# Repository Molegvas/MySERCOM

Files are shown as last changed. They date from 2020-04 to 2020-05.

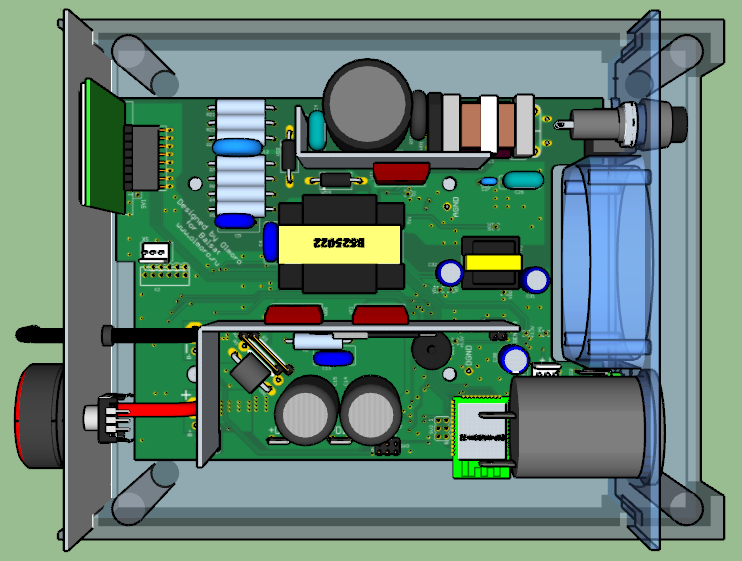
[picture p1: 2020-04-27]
documents/resources/D20v05top.png

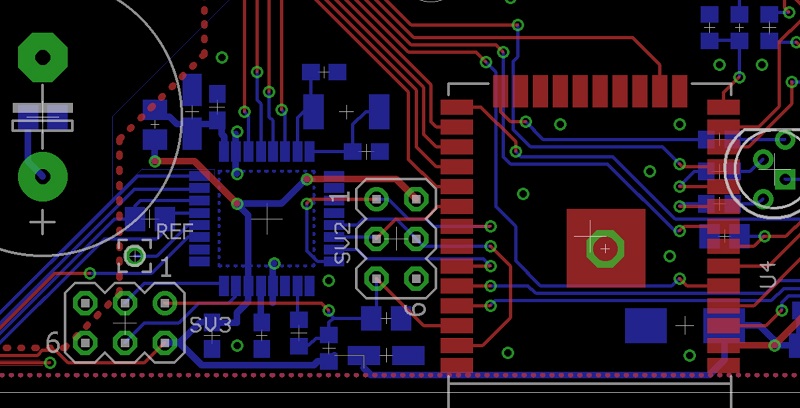
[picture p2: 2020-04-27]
documents/resources/driver.jpg

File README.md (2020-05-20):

#          Адаптер силового блока зарядного устройства

##   Кратко 

Адаптер силового блока предназначен для соединения управляющего контроллера с силовым блоком. Центральный микроконтроллер освобождается от исполнения рутинных операций.

 ### Аппаратная поддержка
   Прототипирование выполнялось на плате SAMD21-M0-Mini. Подробности включения хорошо описаны в https://github.com/BLavery/SAMD21-M0-Mini.
  К сожалению поддержка Arduino не в полной мере соответствует потребностям проекта, но это преодолимо.

 #### Особенности прототипирования на плате SAMD21-M0-Mini
  В качестве инструкции:  https://github.com/BLavery/SAMD21-M0-Mini:
 * select the board: Tools/Board = Arduino SAMD / "Arduino Zero (Native USB Port)".
 * Double-click the board reset button. Upload. See if a LED blinks.
 explain a bit:
 1. The Arduino bootloader uses double click on reset button to enter flash upload mode. Single
    reset enters normal running mode.
 2. The serial/bossac mode of USB upload is included in the Arduino install.
 3. The regular user LED is missing. So we choose one of the TX/RX LEDs. For the moment, 
    the Arduino sketch is NOT otherwise driving these as TX/RX indicators (see above), 
    so we can re-employ them.
 4. But what pin or GPIO number? For this board, reference the pins as 0-26 or A0-A5. Not D25, 
    nor PB03 or PB3.

 ### Обмен между контроллерами.

*  Протокол WAKE является логическим уровнем интерфейса управления оборудованием с помощью асинхронного последовательного канала. Физический уровень интерфейса протоколом не определяется, может использоваться, например, RS-232, RS-485 или USB. Протокол позволяет производить обмен пакетами данных (data frames) длиной до 255 байт с адресуемыми устройствами, которых может быть до 127. Формат данных может быть любым. Могут передаваться байтовые поля, многобайтовые слова или строки символов. Для контроля правильности передачи данных используется контрольная сумма (CRC-8).
* Подробная информация о WAKE: http://leoniv.diod.club/articles/wake/wake.html
Выбор этого протокола объясняется тем, что хорошо известен автору и многолетней работой доказал свою надежность в устройстве ротации кондиционеров.
* Первоначальные планы использовать в качестве физического носителя SPI разбились о прозу жизни - в наличии не оказалось соответствующего адаптера USB-3SPI. Для целей прототипирования используется USB-UART терминал WakeUp! от Ридико Леонида Ивановича. Найдете в "resources".
* Передача параметров из нескольких байт: сначала старший, потом младшие.
* Время ожидания ответа ограничено 1000мс.  

 ### Управление измерениями.

 #### Измерение напряжения
   Измерение напряжения предполагается в диапазоне от -0,2В до +20,0В. Режим АЦП - дифференциальный. Опорное напряжение и усиление - выбор есть. Если получится реализовать вариант со сдвигом по напряжению на 200мВ минусовой клеммы, то обработка неправильной полярности подключения не потребует аппаратной поддержки. 

 #### Измерение тока
   Измерение тока в диапазоне от -16 до +16 ампер на токоизмерительном шунте укладывается в диапазон входного напряжения от -160 до +160мВ. Режим АЦП - дифференциальный. Пороги аварийного отключения не выставлялись.
 #### Измерение тока разряда
Зарезервировано. 
 #### Измерение температуры
Для датчика типа MF52 B 3950 NTC термистор 2% 10 kOm, последовательно резистор 10 kOm, запитан от 3,3в.
Параметры по умолчанию и задаваемые командой 0x57:

| bits | ref | gain | sampl | div | comp | offset | ser Ohm | nom Ohm |
|---|-----|---|---|-----|---|---|---|---|
|  01  |  00 |  00  | 03  |  04 |  00  |  0000  |  2710 | 2710  |

Ответ: код АЦП (2 байта) и значение температур, умноженное на 100.
Вычисления производятся по формуле Стейнхарта.

* Конфигурирование канала измерения состоит из параметров АЦП (разрядность, усреднение, см. страницы 853 и 862) и датчика (опорное напряжение, усиление, приборное смещение, коэффициент преобразования данных в физическую величину).
* В ответ контроллер отправляет пакет, содержащий байт ошибки (зарезервированная позиция), двухбайтный код АЦП и двухбайтное значение измеренной величины (для напряжения - в милливольтах).
* Команды такого типа скорее исследовательские, служащие для поиска оптимальных конфигураций.
* Выбор параметров, предложенных в datasheet ... как говорится, "не все йогурты одинаково полезны" ... 
* Аппаратное смещение задается отдельной командой, усиление - не исследовалось.      
* Ниже дано пояснение формата команды на примере конфигурирования измерителя напряжения.
```c++
// Настройка измерителя напряжения (код команды 0x55  'cmd_set_adc_bat')     
void doAdcBat()
{
    if( rxNbt == 10 )		  // Проверка получения полного пакета
  {
    uint8_t err           = 0x00;
    constexpr uint8_t prb = 0x00; // Измеритель напряжения, в [] - ориентировочные параметры
      // Задать все параметры измерителя [ 01 00 00 03 04 00 0000 12BA ]
    adcBits     [prb] = rxDat[0]; // Разрешение: 0x00(12), [0x01(16)], 0x02(10),  0x03(8)
    prbReference[prb] = rxDat[1]; // Опорное:   [0x00(1V)], 0x01(1/1.48VDDA),     0x02(1/2VDDA), 0x03(ExtA)
    prbGain     [prb] = rxDat[2]; // Усиление:  [0x00(X1)], 0x01(X2),  0x03(X4),  0x04(X8),      (X16), (DIV2)    
    adcSamples  [prb] = rxDat[3]; // Накопление: 0x00(1),   0x01(2),   0x02(4),  [0x03(8)],      0x04(16), ... 0x0a
    adcDivider  [prb] = rxDat[4]; // Делитель:   0x00(2^0), 0x01(2^1), 0x02(2^2), 0x03(2^3),    [0x04(2^4)]... 0x07
    refComp    = 0x01 & rxDat[5]; // 0/1: выкл/вкл аппаратное смещение АЦП
    prbOffset   [prb] = get16(6); // Приборное смещение: 0x8000 ... 0x7fff
    prbDivider  [prb] = get16(8); // Коэффициент преобразования в милливольты:   [0x12ba]
      // Считать результат
                                          // Нулевой байт - ошибка параметра (зарезервировано)
    txDat[1] = ( adcVoltage >> 8) & 0xFF; // Hi
    txDat[2] =   adcVoltage       & 0xFF; // Lo
    txDat[3] = ( voltage >> 8)    & 0xFF; // Hi
    txDat[4] =   voltage          & 0xFF; // Lo

    txReplay( 5, err );		  // Ответ из 5 байт
  }
  else
  {
    txReplay(1, err_tx);	  // Передается код ошибки протокола
  }
}
```

 ### Управление процессами
   Управление производится через два регистра состояния (они же и регистры управления)
 #### state1
* _switchStatus          - управление коммутатором в цепи плюсовой клеммы (foff_pin)
* _converterStatus       - управление преобразователем UC3845
* _currentControlStatus  - пид-регулирование по току
* _voltageControlStatus  - пид-регулирование по напряжению
* _chargeStatus          - управление переключением аналогового выхода на заряд или разряд
* _dischargeStatus       - состояние заряд/разряд
* _pauseStatus           - пауза
* _pidStatus        	 - управление регулятором

 #### state2
* _overHeatingStatus     - состояние перегрева
* _overloadStatus        - состояние перегрузки
* _powerLimitationStatus - состояние ограничения мощности
* _reversePolarityStatus - состояние "обратная полярность"
* _shortCircuitStatus    - состояние "короткое замыкание"
* _calibrationStatus     - состояние калибровки
* _upgradeStatus         - обновление
* _reserve2Status        - резерв 2

 ### Команды управления процессами
 * 0x60 - тестовая - управление коммутатором
 * 0x61 - тестовая - управление преобразователем
 * 0x62 - тестовая - прямое управление преобразователем по напряжению
 * 0x63 - тестовая - прямое управление преобразователем по току
 * 0x64 - 

 ### PID-регулирование.

  Для прототипирования выбран быстрый 32-битный пид-регулятор с фиксированной точкой для Arduino:
FastPID v1.3.1 by Mike Matera 
https://github.com/mike-matera/FastPID

  Этот пид-регулятор работает быстрее, поскольку он позволяет избежать дорогостоящих операций с плавающей запятой. Пид-регулятор сконфигурирован с коэффициентами с плавающей запятой и переводит их в фиксированную точку внутренне. Это накладывает ограничения на область применения коэффициентов. Установка условий I и D на ноль ускоряет работу регулятора. Регулятор сконфигурирован для работы на фиксированной частоте, и вызывающий код отвечает за работу на этой частоте. Параметры Ki и Kd масштабируются по частоте, чтобы сэкономить время во время операции step(). 

 #### Описание коэффициентов регулирования

  * Kp - пропорциональный 
  * Ki - интегральный 
  * Kd - дифференциальный 
  * Hz - частота выполнения контроллера 

#### Диапазон значений коэффициентов 

Конвейер вычислений ожидает 16-битные коэффициенты. Это контролируется PARAM_BITS и не должно быть изменено, иначе может возникнуть нежелательное переполнение. Количество битов до и после десятичного знака контролируется параметром PARAM_SHIFT в FastPID.h. значение по умолчанию для PARAM_SHIFT равно 8 и может быть изменено в соответствии с вашим приложением.

  * Диапазон параметра P от 0.00390625 до 255 включительно.** 
  * Параметр I равен P / Hz** 
  * Параметр D равен P * Hz** 
* ** До выяснения реальной потребности в диапазоне диапазон P установлен от 0,01 до 255.
Регулятор проверяет наличие нарушений диапазона параметров и не будет работать, если коэффициент находится вне диапазона. Все операции конфигурации возвращают bool, чтобы предупредить пользователя об ошибке. Функция err() проверяет состояние ошибки. Ошибки можно устранить с помощью функции clear().

#### Частота Выполнения

* ** Частота выполнения не определяется автоматически, это значительно повышает производительность регулятора. Вместо этого Ki и Kd масштабируются на этапе настройки. Очень важно вызывать step() с той скоростью, которую вы укажете. 

#### Вход и выход

Входной сигнал и заданное значение являются int16_t, что соответствует разрядности АЦП и позволяет разместить отрицательные показания и заданные значения. Выходные данные PID - это int16_t. Фактическая битовая ширина и знаковость вывода могут быть настроены. 
  
  * bits - выходная ширина будет ограничена значениями внутри этого битового диапазона. Допустимые значения от 1 до 16 
  * sign если true, то выходной диапазон равен от -2^(бит-1) до -2^(бит-1) -1. Если выходной диапазон false, то от 0 до 2^(бит-1)-1. 
  * ** Максимальное выходное значение контроллера -32767 (даже в 16-битном беззнаковом режиме) ** 

#### Исполнение

Производительность FastPID варьируется в зависимости от коэффициентов. Когда коэффициент равен нулю, выполняется меньший расчет. Проверено: менее 10мкс. 

#### ПРИКЛАДНОЙ ПРОГРАММНЫЙ ИНТЕРФЕЙС (API)
Здесь и далее приводится авторский текст из указанного первоисточника с незначительными изменениями.

API стремится быть простым и понятным. Я не буду имплицировать функции в регуляторе, которые были бы лучше реализованы вне его.
```c++
FastPID()
```
Создайте контроллер по умолчанию. Все коэффициенты по умолчанию равны нулю. Не используйте сконструированный по умолчанию контроллер до тех пор, пока вы не вызовете setCoefficients() и setOutputconfig()

```c++
FastPID(float kp, float ki, float kd, float hz, int bits=16, bool sign=false)
```
Постройте контроллер, который готов к работе. Вызывает следующие вызовы:
```c++
configure(kp, ki, kd, hz, bits, sign);

bool setCoefficients(float kp, float ki, float kd, float hz);
```
Настройка ПИД коэффициентов. Коэффициенты ki и kd масштабируются на величину hz. Значение hz информирует PID о скорости, которую вы назовете step(). Вызывающий код отвечает за вызов step() со скоростью в hz. Возвращает значение false, если произошла ошибка конфигурации. Что может быть связано с предыдущим вызовом.

bool setOutputConfig(int bits, bool sign);

Установите конфигурацию ouptut по битам/знаку. Диапазон выхода будет следующим:

Для знака, равного true  2^(n-1) - 1 вниз до -2^(n-1)

Для знака, равного false  2^n-1 вниз до 0

* ** bits равен 16-это особый случай. 
* ** Когда bits равен 16 и знак false диапазон выходных напряжений 32767 до 0

Возвращает значение false, если произошла ошибка конфигурации. Что может быть связано с предыдущим вызовом.
```c++
bool setOutputRange (int16_t min, int16_t max);
```
Установите диапазон ouptut непосредственно. Эффективный диапазон действия составляет:

* Мин:  от -32768 до 32766
* Макс: от -32767 до 32767

Min должно быть больше, чем max.

Возвращает значение false, если произошла ошибка конфигурации. Что может быть связано с предыдущим вызовом.
```c++
void clear();
```
Перезагрузите контроллер. Это должно быть сделано до того, как вы каким-либо образом измените конфигурацию.
```c++
bool configure(float kp, float ki, float kd, float hz, int bits=16, bool sign=false);
```
Массовая настройка контроллера. Эквивалентный:
```c++
clear();
setCoefficients(kp, ki, kd, hz);
setOutputConfig(bits, sign);

int16_t step(int16_t sp, int16_t fb);
```
Выполните один шаг контроллера и верните следующий вывод.
```c++
bool err();
```
Проверьте наличие ошибки конфиурации. Контроллер не будет работать, если эта функция возвращает true. 

#### Целочисленный Завод 

Приложения, которые управляют медленно движущимися системами и имеют ненулевой интегральный член, часто видят значительное превышение при запуске. 
Это вызвано интегральной суммой winidng up, поскольку она помнит долгое время вдали от заданной точки. Если это описывает вашу систему есть две вещи, которые вы можете сделать. 

##### Заводную решение: ограничить сумму 

В FastPID есть константы.h, которые контролируют максимально допустимый Интеграл. Понижение этих параметров предотвращает выход контроллера из строя. 
запоминание как можно большего смещения от заданного значения и позволит уменьшить превышение. 
```c++
#define INTEG_MAX    (INT32_MAX)
#define INTEG_MIN    (INT32_MIN)
```
Меняйте эти константы с осторожностью. Установка их слишком низко исправит вашу проблему превышения скорости, но это негативно скажется на способность регулятора регулировать нагрузку. Если вы не уверены в правильной константе используйте следующее решение вместо этого ограничения суммы. 

#### Ограничение Заводки: Ограниченное Регулирование 

Пид-контроллер лучше всего работает, когда система находится близко к заданному значению. Во время фазы запуска или в случае с a 
значительная экскурсия, вы можете полностью отключить пид-контроль. Пример этого можно найти в контроллере Sous-Vide 
пример в этом проекте. Ядро логики находится в этом коде: 
```c++
if (feedback < (setpoint * 0.9)) {
  analogWrite(PIN_OUTPUT, 1);
  myPID.clear();
}
else {
  analogWrite(PIN_OUTPUT, myPID.step(setpoint, feedback));
}
```
Код обходит ПИД, когда температура составляет менее 90% от заданного значения, просто включив нагреватель. Когда 
температура выше 90% от заданного значения пид включен. Фиксация вашего промаха таким образом дает вам гораздо лучший контроль
вашей системы без необходимости добавлять сложные, недопустимые и трудные для понимания функции к пид-контроллеру.

#### Sample Code 
```c++
#include <FastPID.h>

#define PIN_INPUT     A0
#define PIN_SETPOINT  A1
#define PIN_OUTPUT    9

float Kp=0.1, Ki=0.5, Kd=0.1, Hz=10;
int output_bits = 8;
bool output_signed = false;

FastPID myPID(Kp, Ki, Kd, Hz, output_bits, output_signed);

void setup()
{
  Serial.begin(9600);
  if (myPID.err()) {
    Serial.println("There is a configuration error!");
    for (;;) {}
  }
}

void loop()
{
  int setpoint = analogRead(PIN_SETPOINT) / 2; 
  int feedback = analogRead(PIN_INPUT);
  int ts = micros();
  uint8_t output = myPID.step(setpoint, feedback);
  int tss = micros();
  analogWrite(PIN_OUTPUT, output);
  Serial.print("(Fast) micros: "); 
  Serial.print(tss - ts);
  Serial.print(" sp: "); 
  Serial.print(setpoint); 
  Serial.print(" fb: "); 
  Serial.print(feedback);
  Serial.print(" out: ");
  Serial.println(output);
  delay(100);
}
```
### Справочная информация (подлежит уточнению)

|  код  | имя | параметры | пример (данные, hex) |
|---|---|---|---|
| ответ	| 			  | cmd_err  			 | ошибка приема пакета |

#### Команды АЦП-преобразований

|  код  | имя | параметры | пример (данные, hex) |
|---|---|---|---|
| 0x50	| cmd_adc_read_probes | | |
| ответ	| 			  | adcU_h,l, adcI_h,l, 	 | 1F 00 1F 00 |
| 	| 			  | adcD_h,l, adcC_h,l, | 1F 00 1F 00 |
| | | mcr1, mcr2 | 00 FF |
| 0x52	| cmd_adc_config52 | nPrb, gain, ref, offset, mult | 01 00 02 00 00 01 00 |
| ответ	| 			  | | 00 |
| 0x53	| cmd_adc_config53 | nPrb, bits, samples, divider | 01 01 02 03 |
| ответ	| 			  | | 00 |
| | | | | 

#### Команды ПИД-регулятора

|  код  | имя | параметры | пример (данные, hex) |
|---|---|---|---|
| 0x40	| cmd_pid_configure | kp, ki, kd, hz, bits, sign | 00 19 00 80 00 00 0A 00 00 0A 00 |
| ответ	| 			  | 00 / 0x40 | OK / ошибка параметра |
| 0x41	| cmd_pid_coefficients | kp, ki, kd, hz | 00 19 00 80 00 00 0A 00 |
| ответ	| 			  | 00 / 0x40 | OK / ошибка параметра |
| 0x42	| cmd_pid_output_range | min, max | 00 00 03 FF |
| ответ	| 			  | 00 / 0x40 | OK / ошибка параметра |
| 0x43	| cmd_pid_output_config | bits, sign | 10 00 |
| ответ	| 			  | 00 / 0x40 | OK / ошибка параметра |
| 0x44	| cmd_pid_clear | | |
| ответ	| 			  | 00 / 0x40 | OK / ошибка параметра |
| 0x45	| cmd_pid_stop_go | (стоп-пауза-пуск) | |
| ответ	| 			  | 00 / 0x40 | OK / ошибка |
| 0x46	| cmd_pid_test | res, mode, setpoint, min, max | FF 03 01 FF 00 00 03 FF |
| ответ	| 			  | 00 / 0x40 | OK / ошибка параметра |
| 0x47	| | | |
| | | | | 
* kp, ki, kd, hz - целочисленные, полученные умножением на 256 (т.е << 8)

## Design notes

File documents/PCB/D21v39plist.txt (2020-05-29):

Partlist

Exported from D21_v39.sch at 29.05.2020 8:06

EAGLE Version 7.3.0 Copyright (c) 1988-2015 CadSoft

Assembly variant: 

Part     Value                    Device                        Package               Library                Sheet

(X2)                              MA05-1                        MA05-1                con-lstb_moro          3
+        +                        WIREPAD8_3                    WIREPAD8_3            Q921s                  3
+3.3V                             WIREPAD1,6/0,8                1,6/0,8               wirepad                2
+5.5V                             WIREPAD1,6/0,8                1,6/0,8               wirepad                2
-        -                        WIREPAD8_3                    WIREPAD8_3            Q921s                  3
5        TPB1,27                  TPB1,27                       B1,27                 testpad                1
AGND                              WIREPAD4,16O1,6               4,16O1,6              wirepad                1
B+                                WIREPAD4,16O1,6               4,16O1,6              wirepad                3
B-                                WIREPAD4,16O1,6               4,16O1,6              wirepad                3
C1       473K 275V                C-EU150-054X183               C150-054X183          rcl_moro               1
C2       473K 275V                C-EU150-054X183               C150-054X183          rcl_moro               1
C3       220mkF 400V              CPOL-EUE10-25                 EB25D                 rcl_moro               1
C4       10nF 2KV                 C-EU102-043X133               C102-043X133          rcl_moro               1
C5       4.7nF ± 10% 2KV          C-EU102-064X133               C102-064X133          rcl_moro               1
C6       JEC JY222M               C-EU102-064X133               C102-064X133          rcl_moro               1
C6.1     JEC JY222M               C-EU102-064X133               C102-064X133          rcl_moro               1
C7       100nF X7R                C-EUC0603                     C0603                 rcl_moro               1
C8       1nF NP0                  C-EUC0603                     C0603                 rcl_moro               1
C9       100nF X7R                C-EUC0603                     C0603                 rcl_moro               1
C10      100nF X7R                C-EUC0805                     C0805                 rcl_moro               1
C11      470pF X7R                C-EUC0603                     C0603                 rcl_moro               1
C12      0.15nF 2kV               C-EU075-032X103               C075-032X103          rcl_moro               1
C13      4.7nF 1KV                C-EU102-064X133               C102-064X133          rcl_moro               1
C14      4700mkF 35V              CPOL-EUE7.5-18                E7,5-18               rcl_moro               1
C15      4700mkF 35V              CPOL-EUE7.5-18                E7,5-18               rcl_moro               1
C16      1mkF X7R 50V             C-EUC0805                     C0805                 rcl_moro               1
C17      1mkF X7R 50V             C-EUC0805                     C0805                 rcl_moro               1
C19      100nF X7R                C-EUC0603                     C0603                 rcl_moro               1
C20      10nF 2KV                 C-EU102-043X133               C102-043X133          rcl_moro               2
C21      68pF 2KV (82pF)          C-EU050-024X044               C050-024X044          rcl_moro               2
C22      100nF X7R                C-EUC0603                     C0603                 rcl_moro               2
C23      TAJB106K025RNJ           CPOL-EUCT6032                 CT6032                rcl_moro               2
C24      100nF X7R                C-EUC0603                     C0603                 rcl_moro               2
C25      220uF 35v                CPOL-EUE3.5-8                 E3,5-8                rcl_moro               2
C26      470nF X7R                C-EUC0805                     C0805                 rcl_moro               2
C27      220uF 35v                CPOL-EUE3.5-8                 E3,5-8                rcl_moro               2
C28      100nF X7R                C-EUC0805                     C0805                 rcl_moro               2
C29      1mkF X7R                 C-EUC0805                     C0805                 rcl_moro               2
C30      T491A106K035AT           CPOL-EUCT6032                 CT6032                rcl_moro               2
C31      470pF X7R                C-EUC0603                     C0603                 rcl_moro               2
C32      470uF 16v                CPOL-EUE5-8.5                 E5-8,5                rcl_moro               2
C33      T491A106K010AT           CPOL-EUCT3216                 CT3216                rcl_moro               2
C34      T491A106K010AT           CPOL-EUCT3216                 CT3216                rcl_moro               2
C35      100nF X7R                C-EUC0603                     C0603                 rcl_moro               2
C36      100nF X7R                C-EUC0603                     C0603                 rcl_moro               2
C37      TAJB336K010RNJ           CPOL-EUCT6032                 CT6032                rcl_moro               3
C38      470nF X7R                C-EUC0805                     C0805                 rcl_moro               3
C39      470nF X7R                C-EUC0805                     C0805                 rcl_moro               3
C43      470nF X7R                C-EUC0805                     C0805                 rcl_moro               3
C44      1mkF X7R                 C-EUC0805                     C0805                 rcl_moro               3
C45      TAJC107K006RNJ           CPOL-EUCT3528                 CT3528                rcl_moro               3
C46      3.3uF X7R                C-EUC0603                     C0603                 rcl_moro               3
C47      470mkF 25v               CPOL-EUE3.5-8                 E3,5-8                rcl_moro               3
C48      470nF X7R                C-EUC0805                     C0805                 rcl_moro               4
C49      T491A106K010AT           CPOL-EUCT3216                 CT3216                rcl_moro               4
C50      100nF X7R                C-EUC0603                     C0603                 rcl_moro               4
C51      15pF X7R                 C-EUC0603                     C0603                 rcl_moro               4
C52      15pF X7R                 C-EUC0603                     C0603                 rcl_moro               4
C53      100nF X7R                C-EUC0603                     C0603                 rcl_moro               4
C54      100nF X7R                C-EUC0603                     C0603                 rcl_moro               4
C55      100nF X7R                C-EUC0805                     C0805                 rcl_moro               4
CH                                WIREPAD1,6/0,8                1,6/0,8               wirepad                4
DAC                               WIREPAD1,6/0,8                1,6/0,8               wirepad                4
DGND                              WIREPAD4,16O1,6               4,16O1,6              wirepad                1
DIN                               WIREPAD1,6/0,8                1,6/0,8               wirepad                4
DVT1     PDTA123ET                MUN2113T1                     SC59-BEC              transistor-pnp         3
DVT2     PDTD123ET                BCR108                        SOT23-BEC             digital-transistors    3
DVT3     PDTD123ET                BCR108                        SOT23-BEC             digital-transistors    3
FB1      BLM21AG221SN1D           FERRITE0805                   0805                  microbuilder_v2        4
FOFF                              WIREPAD1,6/0,8                1,6/0,8               wirepad                4
IO19                              TESTPOINTROUND1MM             TESTPOINT_ROUND_1MM   microbuilder_v2        3
IO23                              TESTPOINTROUND1MM             TESTPOINT_ROUND_1MM   microbuilder_v2        3
L1       PLA10AN1522R0R2          DK_Q921                       DK30                  Q921                   1
L2       SD74R-221                DR74                          DR74                  inductors              2
LED      5mm RGB LED common anode 5MMRGBLED                     LED5MMRGB             led_rgb                3
LEDG     LED3MM-GREEN             LED3MM-H7MMG                  LED3MM-H7MMG          moro4                  2
LEDR     LED3MM-RED               LED3MM-H7MMR                  LED3MM-H7MMR          moro4                  2
MI                                WIREPAD4,16O1,6               4,16O1,6              wirepad                1
O1                                WIREPAD1,6/0,8                1,6/0,8               wirepad                1
OPTV1    K10104C                  SFH618A-3X007                 SMD4-7                optocoupler            1
OPTV2    K10104C                  SFH618A-3X007                 SMD4-7                optocoupler            1
OPTV3    K10104C                  SFH618A-3X007                 SMD4-7                optocoupler            2
OPTV4    K10104C                  SFH618A-3X007                 SMD4-7                optocoupler            3
OPTV5    K10104C                  SFH618A-3X007                 SMD4-7                optocoupler            3
PA22                              TESTPOINTROUND1MM             TESTPOINT_ROUND_1MM   microbuilder_v2        4
PA28                              TESTPOINTROUND1MM             TESTPOINT_ROUND_1MM   microbuilder_v2        4
PAD1                              SMD2                          SMD1,27-2,54          wirepad                1
PAD2                              SMD2                          SMD1,27-2,54          wirepad                1
PAD3                              SMD2                          SMD1,27-2,54          wirepad                1
PAD4                              WIREPAD4,16O1,6               4,16O1,6              wirepad                1
PG                                WIREPAD1,6/0,8                1,6/0,8               wirepad                2
PL                                WIREPAD4,16O1,6               4,16O1,6              wirepad                1
R1       15S-1.3                  15S-1.3                       15S-1.3               Q921                   1
R2       15S-1.3                  15S-1.3                       15S-1.3               Q921                   1
R3       15S-1.3                  15S-1.3                       15S-1.3               Q921                   1
R4       12k ± 5%                 R-0515/20                     0515/20               Q921                   1
R5       12k ± 5%                 R-0515/20                     0515/20               Q921                   1
R6       12k ± 5%                 R-0515/20                     0515/20               Q921                   1
R7       12k ± 5%                 R-0515/20                     0515/20               Q921                   1
R8       39 Om ± 5%               R-0515/20                     0515/20               Q921                   1
R9       9k1 1%                   R-EU_R0603                    R0603                 rcl_moro               1
R10      10k                      R-EU_R0603                    R0603                 rcl_moro               1
R11      2k2                      R-EU_R0603                    R0603                 rcl_moro               1
R12      10k                      R-EU_R0603                    R0603                 rcl_moro               1
R13      1R0                      R-EU_R0805                    R0805                 rcl_moro               1
R14      5R1                      R-EU_R0805                    R0805                 rcl_moro               1
R15      1k                       R-EU_R0603                    R0603                 rcl_moro               1
R16      10k                      R-EU_R0603                    R0603                 rcl_moro               1
R17      1R0 1%                   R-EU_R2512                    R2512                 rcl_moro               1
R18      1R0 1%                   R-EU_R2512                    R2512                 rcl_moro               1
R19      1R0 1%                   R-EU_R2512                    R2512                 rcl_moro               1
R20      1R0 1%                   R-EU_R2512                    R2512                 rcl_moro               1
R21      1.2k ± 5%                R-0515/20                     0515/20               Q921                   1
R22      1.2k ± 5%                R-0515/20                     0515/20               Q921                   1
R23      1.2k ± 5%                R-0515/20                     0515/20               Q921                   1
R24      470                      R-EU_R0603                    R0603                 rcl_moro               1
R25      470                      R-EU_R0603                    R0603                 rcl_moro               1
R26      5k1                      R-EU_R0603                    R0603                 rcl_moro               1
R27                               R-EU_R0603                    R0603                 rcl_moro               1
R28                               R-EU_R0603                    R0603                 rcl_moro               1
R29                               R-EU_R0603                    R0603                 rcl_moro               1
R30      1R0 1%                   R-EU_R2512                    R2512                 rcl_moro               1
R31      1R0 1%                   R-EU_R2512                    R2512                 rcl_moro               1
R32      1R0 1%                   R-EU_R2512                    R2512                 rcl_moro               1
R33      1R0 1%                   R-EU_R2512                    R2512                 rcl_moro               1
R34      1R0 1%                   R-EU_R2512                    R2512                 rcl_moro               1
R35      1R0 1%                   R-EU_R2512                    R2512                 rcl_moro               1
R36      k75                      R-EU_R1206                    R1206                 rcl_moro               2
R37      k75                      R-EU_R1206                    R1206                 rcl_moro               2
R38      1MOm                     R-EU_R1206                    R1206                 rcl_moro               2
R39      1MOm                     R-EU_R1206                    R1206                 rcl_moro               2
R40      100                      R-EU_R0603                    R0603                 rcl_moro               2
R41      10k0 1%                  R-EU_R0603                    R0603                 rcl_moro               2
R42      1k5 1%                   R-EU_R0603                    R0603                 rcl_moro               2
R43      5k1 1%                   R-EU_R0603                    R0603                 rcl_moro               2
R44      1k 1%                    R-EU_R0603                    R0603                 rcl_moro               2
R45      0R33                     R-EU_R0603                    R0603                 rcl_moro               2
R46      3.0k 1%                  R-EU_R0603                    R0603                 rcl_moro               2
R47      10k 1%                   R-EU_R0603                    R0603                 rcl_moro               2
R48      1K                       R-EU_R0603                    R0603                 rcl_moro               2
R49      1K                       R-EU_R0603                    R0603                 rcl_moro               2
R50      12K                      R-EU_R0603                    R0603                 rcl_moro               2
R51      12K                      R-EU_R0603                    R0603                 rcl_moro               2
R52      150R                     R-EU_R0603                    R0603                 rcl_moro               3
R53      330R                     R-EU_R0603                    R0603                 rcl_moro               3
R54      470R                     R-EU_R0603                    R0603                 rcl_moro               3
R55      1.5k 1%                  R-EU_R0603                    R0603                 rcl_moro               3
R56      k750 1%                  R-EU_R0603                    R0603                 rcl_moro               3
R57      k300 1%                  R-EU_R0603                    R0603                 rcl_moro               3
R58      1k5 1%                   R-EU_R0603                    R0603                 rcl_moro               3
R59      3k0 1%                   R-EU_R0603                    R0603                 rcl_moro               3
R60      7k5 1%                   R-EU_R0603                    R0603                 rcl_moro               3
R61      2.2k                     R-EU_R0603                    R0603                 rcl_moro               3
R62      330                      R-EU_R0603                    R0603                 rcl_moro               3
R63      nu                       R-EU_R0603                    R0603                 rcl_moro               3
R64      330                      R-EU_R0603                    R0603                 rcl_moro               3
R65      330                      R-EU_R0603                    R0603                 rcl_moro               3
R66      2.2k                     R-EU_R0603                    R0603                 rcl_moro               3
R67      68k                      R-EU_R0603                    R0603                 rcl_moro               3
R68      100R                     R-EU_R0603                    R0603                 rcl_moro               3
R69      100R                     R-EU_R0603                    R0603                 rcl_moro               3
R70      10k 1%                   R-EU_R0603                    R0603                 rcl_moro               3
R71      30k                      R-EU_R0603                    R0603                 rcl_moro               3
R72      12k                      R-EU_R0603                    R0603                 rcl_moro               3
R73      470                      R-EU_R0603                    R0603                 rcl_moro               3
R74      4k7                      R-EU_R0603                    R0603                 rcl_moro               3
R75      4k7                      R-EU_R0603                    R0603                 rcl_moro               3
R76      4k7                      R-EU_R0603                    R0603                 rcl_moro               3
R77      39k0 1%                  R-EU_R0603                    R0603                 rcl_moro               4
R78      7k5 1%                   R-EU_R0603                    R0603                 rcl_moro               4
R79      470                      R-EU_R0603                    R0603                 rcl_moro               4
R80      10k                      R-EU_R0603                    R0603                 rcl_moro               4
R81      470??                    R-EU_R0603                    R0603                 rcl_moro               4
R82      100                      R-EU_R0603                    R0603                 rcl_moro               4
R83      100                      R-EU_R0603                    R0603                 rcl_moro               4
R84      10k                      R-EU_R0603                    R0603                 rcl_moro               4
R87      470??                    R-EU_R0603                    R0603                 rcl_moro               4
R89                               R-EU_R0603                    R0603                 rcl_moro               3
R90                               R-EU_R0603                    R0603                 rcl_moro               3
REFA     TPB1,27                  TPB1,27                       B1,27                 testpad                4
RT1      NTC10D-15                THERMISTOR                    NTC15                 varistor_moro          1
RTU                               WIREPAD1,6/0,8                1,6/0,8               wirepad                4
RU1      V275LA20AP               VARISTOR-H                    S10K11-H              varistor_moro          1
S1       FSMSM                    SWITCH-MOMENTARY-2-SMD-1101NE TACTILE-SWITCH-1101NE SparkFun               4
SENSOR                            JP1E                          JP1                   jumper_moro            3
SG1      BMT1205XH7.5             BMT1205XH7.5                  BMT1205XH7.5          buzzer-moro            3
SV1                               FE08-1                        FE08                  con-lsta_moro          3
SV2                               MA03-2                        MA03-2                con-lstb_moro          4
SV3      MA05-2-2MM               MA05-2-2MM                    MA5-2-2MM             con-lstb_moro          4
SW1      SWT-3                    31-XX                         B3F-31XX              switch-omron           3
TP11     TPB1,27                  TPB1,27                       B1,27                 testpad                2
TP12     TPB1,27                  TPB1,27                       B1,27                 testpad                2
TV1      BS25022                  BS25022                       BS25022               Q921                   1
TV2      BS9001                   BS9001                        BS9001                Q921                   2
U1       UC3845B                  UC3845B                       SO08                  moro4                  1
U2       LM321MF                  LM321MF                       SOT23-5               linear                 1
U3       TNY254GN                 TNY254GN                      SMD-8                 moro4                  2
U4       MC34063AD                MC34063AD                     SO08                  v-reg-3                2
U5       LM1117MP-3.3             LM1117SOT223-WAVE             SOT223-W              microbuilder_v2        2
U6       CP2104                   CP2104                        QFN-24                moro4                  2
U8       ESP-WROOM-32 MODULE      ESP-WROOM-32                  ESP-WROOM-32MORO      esp32                  3
U9       WF18FTLAADNN0            TFT_128_128                   TFT_1_8               Q921                   3
U10      ATSAMD21G1XA-A           ATSAMD21G1XA-A                LQFP48_W              atmel_prototype_header 4
VCC                               WIREPAD1,6/0,8                1,6/0,8               wirepad                2
VD+                               WIREPAD1,6/0,8                1,6/0,8               wirepad                2
VD-                               WIREPAD1,6/0,8                1,6/0,8               wirepad                2
VD1      KBP206                   2KBP                          2KBP                  Q921                   1
VD2      SF58                     1N5624                        DO201-15              diode-1                1
VD3      SF58                     1N5624                        DO201-15              diode-1                1
VD4      US1M                     DIODESMA                      SMADIODE              microbuilder (2)       1
VD5      MBR30100PT               MBR30100PT                    TO-247AD-V            Q921 (2)               1
VD6      FR607                    DIODE-P6-15                   P6-15                 diode-1                1
VD7      P6SMB200A                ZENER-DIODESMB                SMB                   diode-1                2
VD8      US1M                     DIODESMA                      SMADIODE              microbuilder_v2        2
VD9      LL4148                   DIODE-SOD80C                  SOD80C                diode                  2
VD10     US1M                     DIODESMA                      SMADIODE              microbuilder_v2        2
VD11     US1M                     DIODESMA                      SMADIODE              microbuilder_v2        2
VD12     US1M                     DIODESMA                      SMADIODE              microbuilder_v2        2
VD13     US1M                     DIODESMA                      SMADIODE              microbuilder_v2        2
VD14     SS16                     DIODESMA                      SMADIODE              microbuilder_v2        2
VD15     SS16                     DIODESMA                      SMADIODE              microbuilder_v2        2
VD16     SS16                     DIODESMA                      SMADIODE              microbuilder_v2        2
VD17     SS16                     DIODESMA                      SMADIODE              microbuilder_v2        2
VD18     BZV55C13                 ZENER-DIODESOD80C             SOD80C                diode-1                3
VD19     LL4148 nu                DIODE-SOD80C                  SOD80C                diode                  3
VD20     US1M                     DIODESMA                      SMADIODE              microbuilder_v2        3
VD21     LL4148                   DIODE-SOD80C                  SOD80C                diode                  3
VD22     LL4148 nu                DIODE-SOD80C                  SOD80C                diode                  4
VD23     SS16                     DIODESMA                      SMADIODE              microbuilder_v2        4
VD24     SS16                     DIODESMA                      SMADIODE              microbuilder_v2        4
VD25     SS16                     DIODESMA                      SMADIODE              microbuilder_v2        2
VDD                               WIREPAD1,6/0,8                1,6/0,8               wirepad                2
VR1      TL431A (TAI 3)           TL431-SOT23-3                 SOT23                 moro4                  2
VT1      STW10NK60Z               STW10NK60Z                    TO-247AD-V            Q921 (2)               1
VT2      IRFP250N                 IRFP25X                       TO-247AD-V            Q921 (2)               1
VT3      BC847C                   NPN-TRANSISTOR_SOT23          SOT23                 semicon-smd-ipc        2
VT4      BC847C                   NPN-TRANSISTOR_SOT23          SOT23                 semicon-smd-ipc        2
VT5      IRF8788                  IRF8788                       SO-8                  transistor-fet_moro    3
VT6      IRF8788                  IRF8788                       SO-8                  transistor-fet_moro    3
VT7      2N7002                   MOSFET-NREFLOW                SOT23-R               microbuilder (2)       1
X1       220VAC                   220VAC                        220VAC                Q921                   1
X2       WF-6 (PLD-10)            WF-6                          WF-6                  moro2                  3
X3       WF-3 (WF-2)              WF-3                          WF-3                  moro2                  3
X4       USB-B                    USB-B-H                       USB-B-H               con-usb-3              2
X5       WF-4                     WF-4                          WF-4                  moro2                  3
X6       USB_MICRO_BF_180         USB_MICRO_BF_180              USB_MICRO_180         microbuilder           4
Y1       FC-135                   FC-135                        SMD03215C2            microbuilder_v2        4

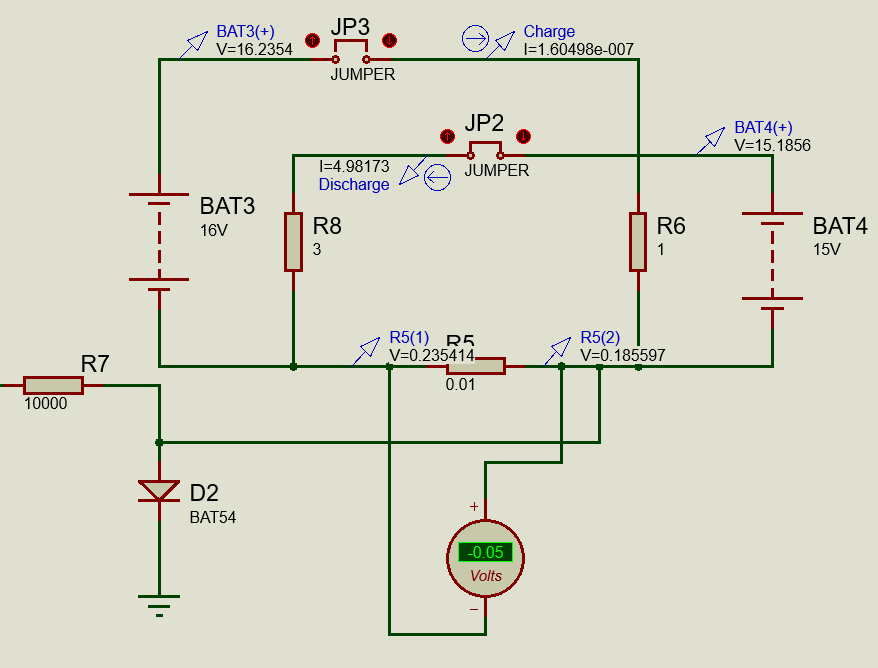
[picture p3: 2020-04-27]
documents/resources/Discharge_5A.png

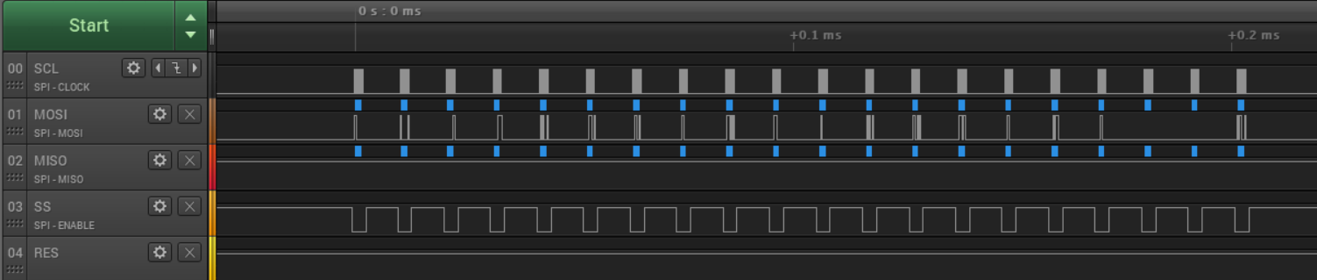
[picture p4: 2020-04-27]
documents/resources/Log.png

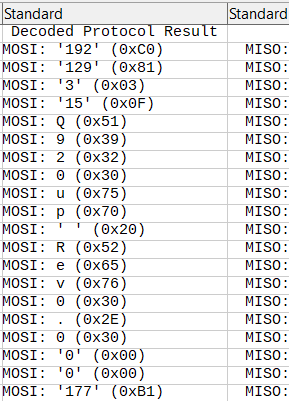
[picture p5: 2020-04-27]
documents/resources/MOSI.png

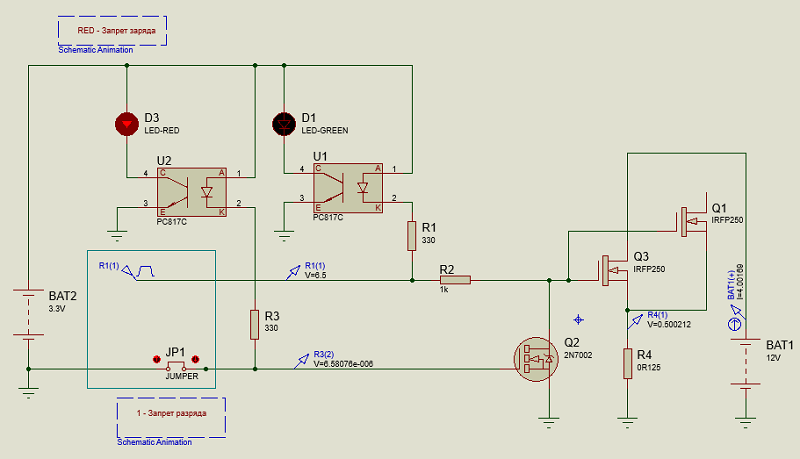
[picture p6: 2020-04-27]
documents/resources/Model.png

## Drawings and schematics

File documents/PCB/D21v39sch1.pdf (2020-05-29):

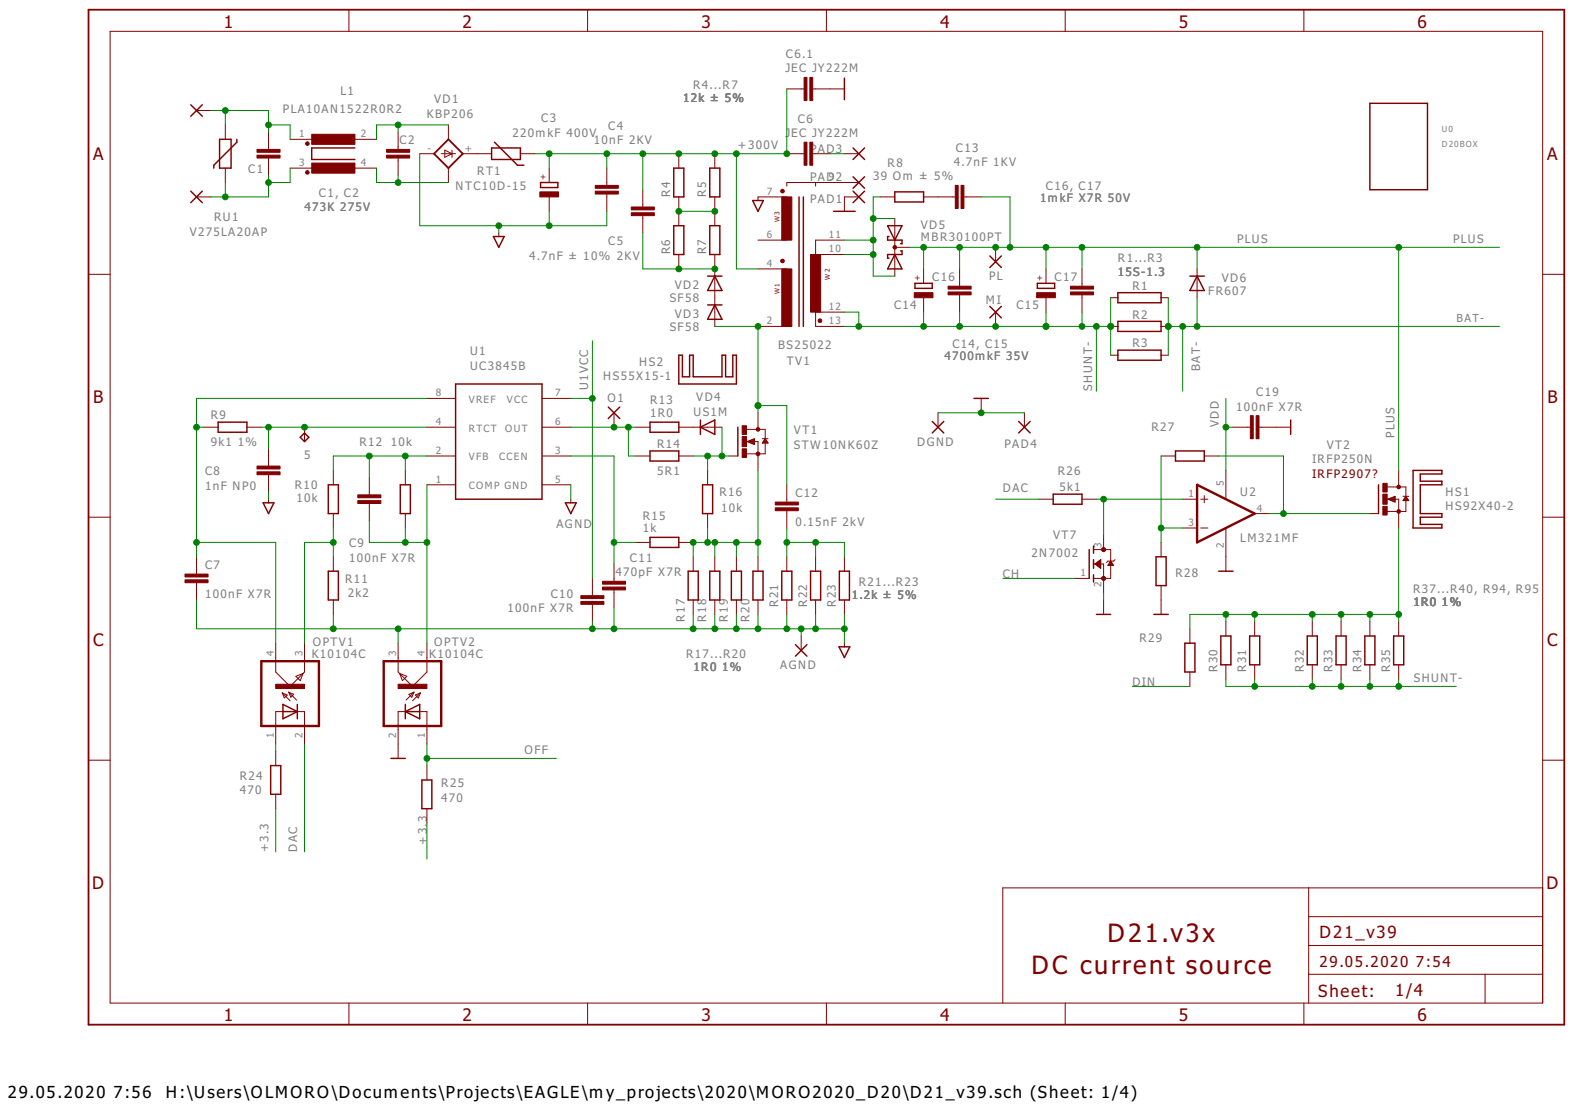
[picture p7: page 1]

DC current source

Sheet: 1/4

29.05.2020 7:56 H:\Users\OLMORO\Documents\Projects\EAGLE\my_projects\2020\MORO2020_D20\D21_v39.sch (Sheet: 1/4)

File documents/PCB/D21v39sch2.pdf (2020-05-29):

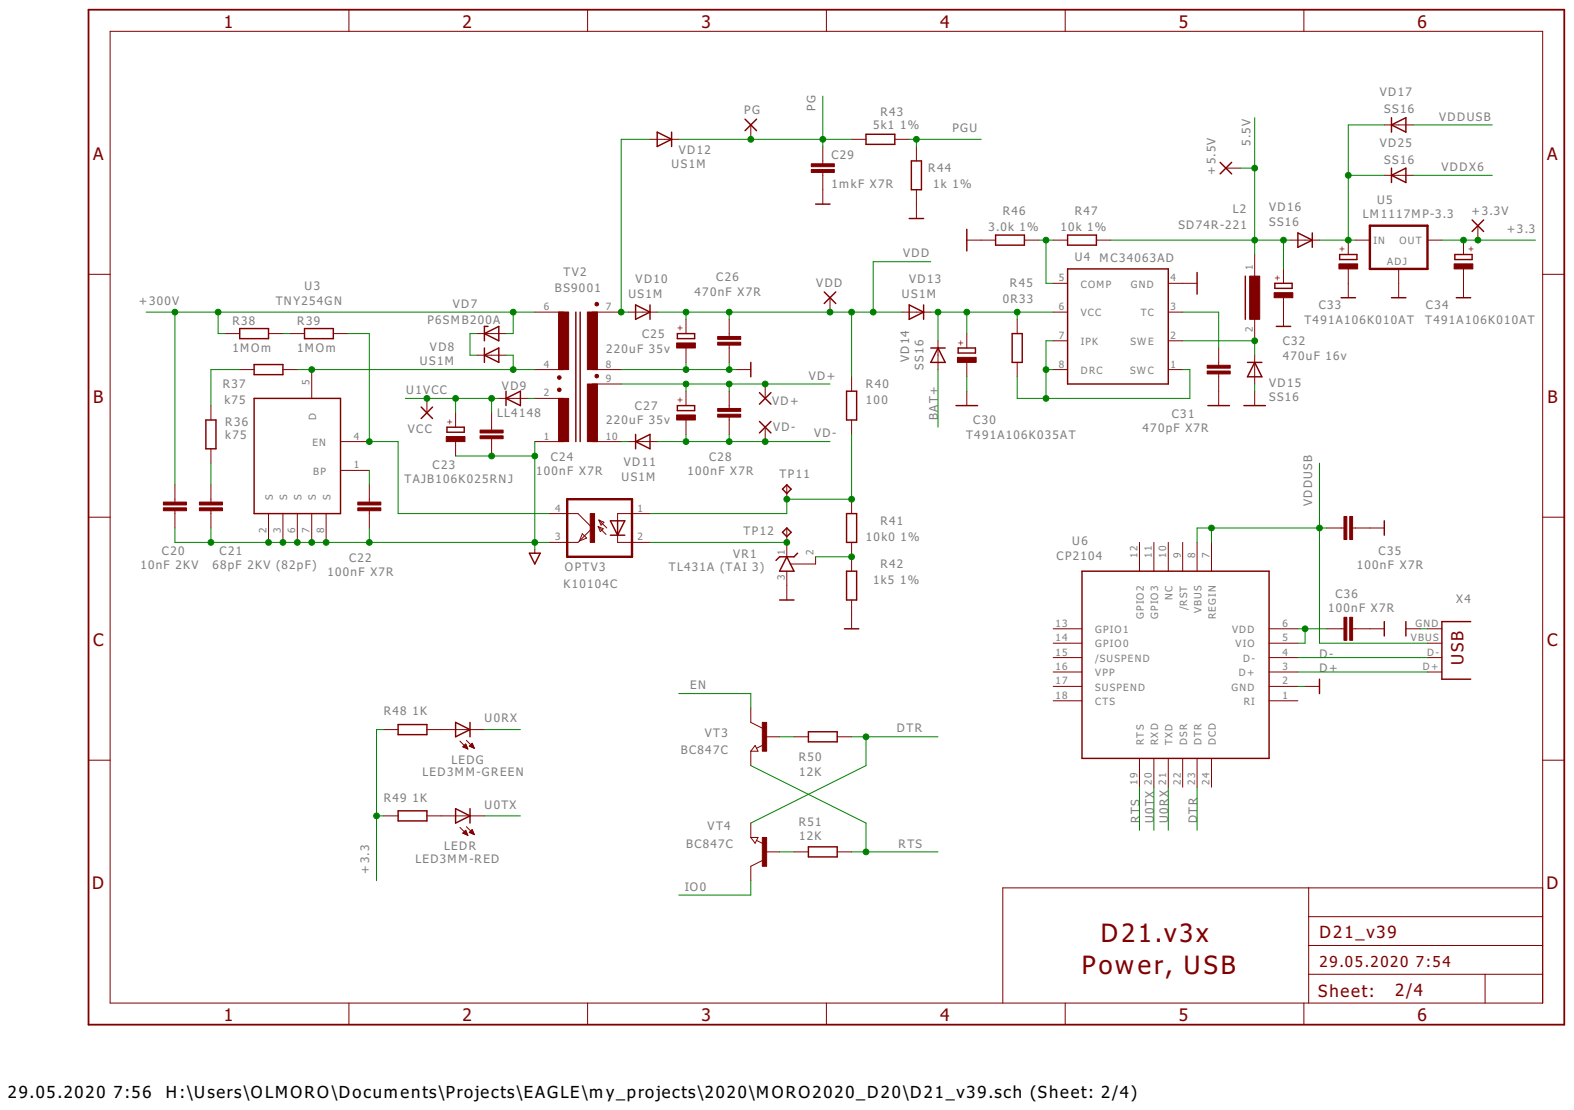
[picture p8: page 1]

D21.v3x Power, USB

Sheet: 2/4

29.05.2020 7:56 H:\Users\OLMORO\Documents\Projects\EAGLE\my_projects\2020\MORO2020_D20\D21_v39.sch (Sheet: 2/4)

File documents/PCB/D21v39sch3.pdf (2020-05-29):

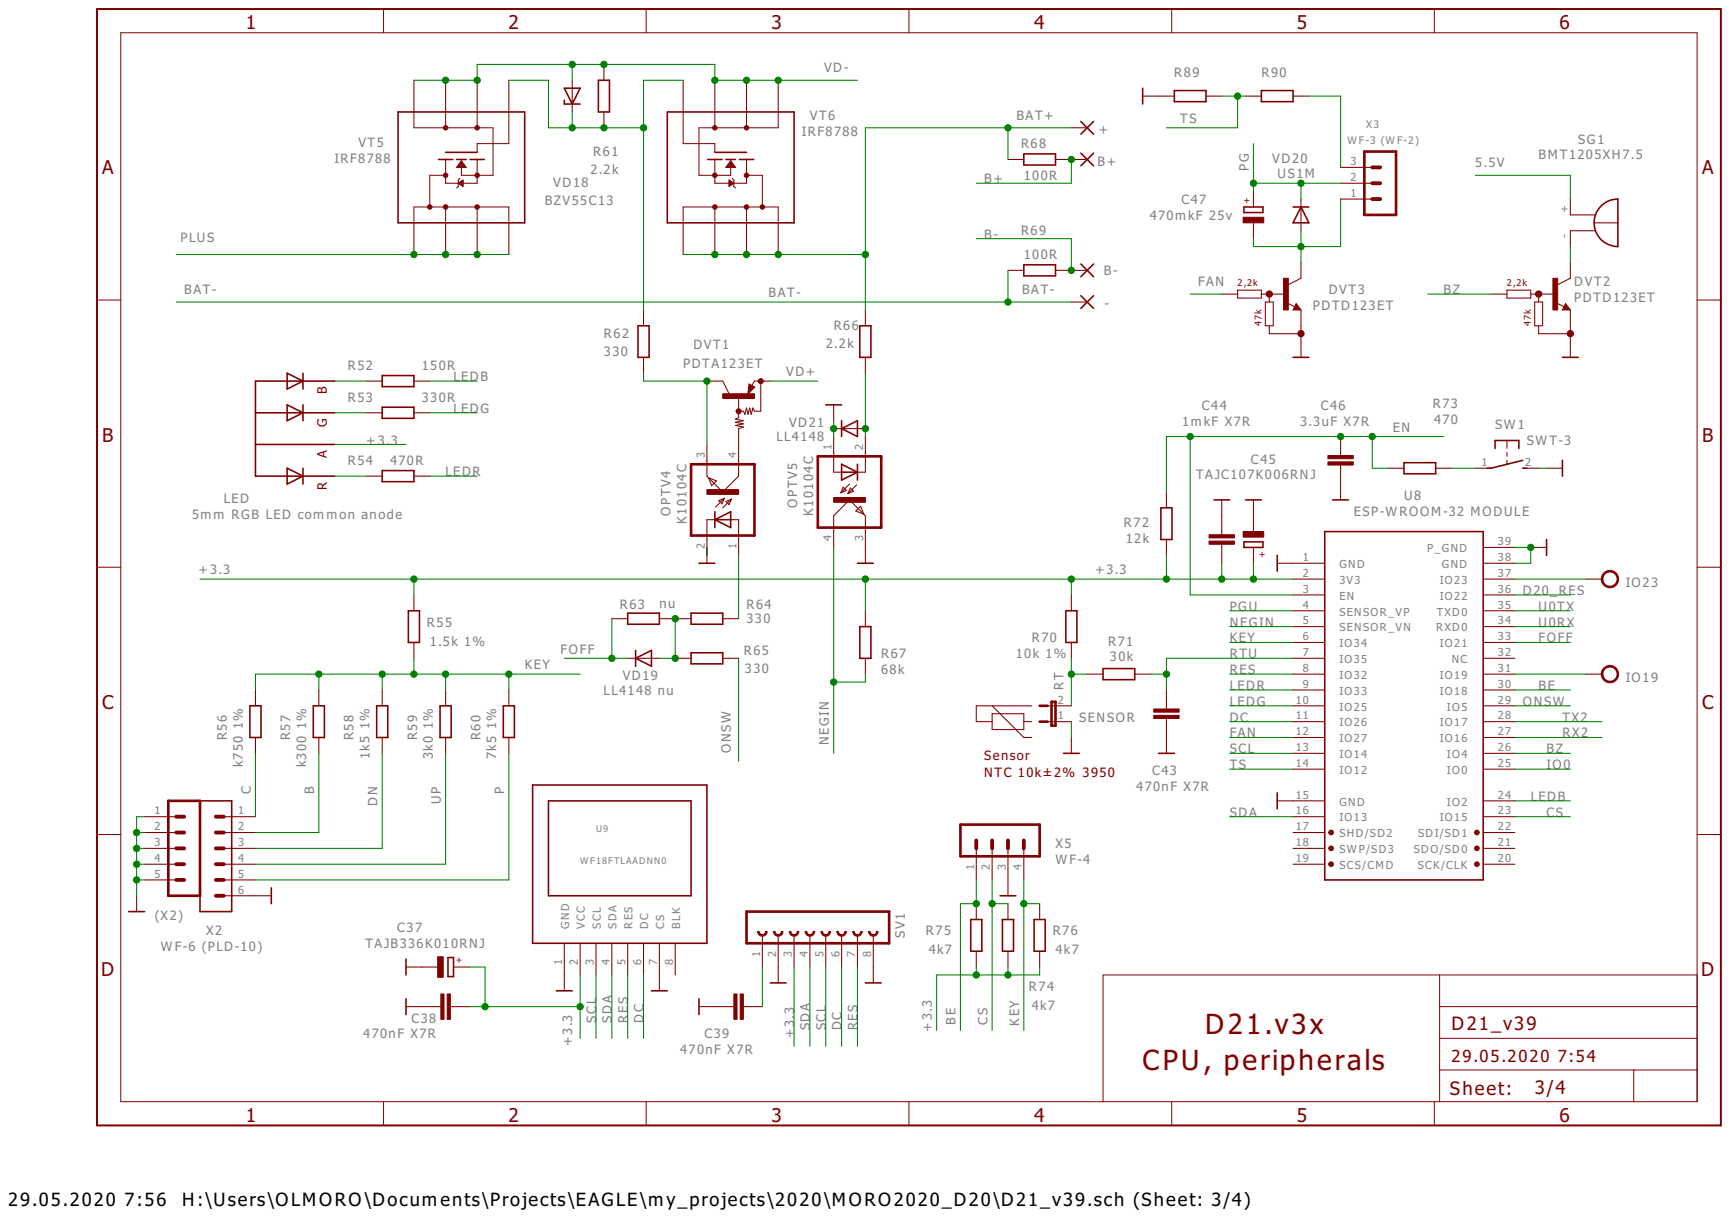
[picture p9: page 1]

LED
5mm RGB LED common anode

D21.v3x CPU, peripherals

Sheet: 3/4

29.05.2020 7:56 H:\Users\OLMORO\Documents\Projects\EAGLE\my_projects\2020\MORO2020_D20\D21_v39.sch (Sheet: 3/4)

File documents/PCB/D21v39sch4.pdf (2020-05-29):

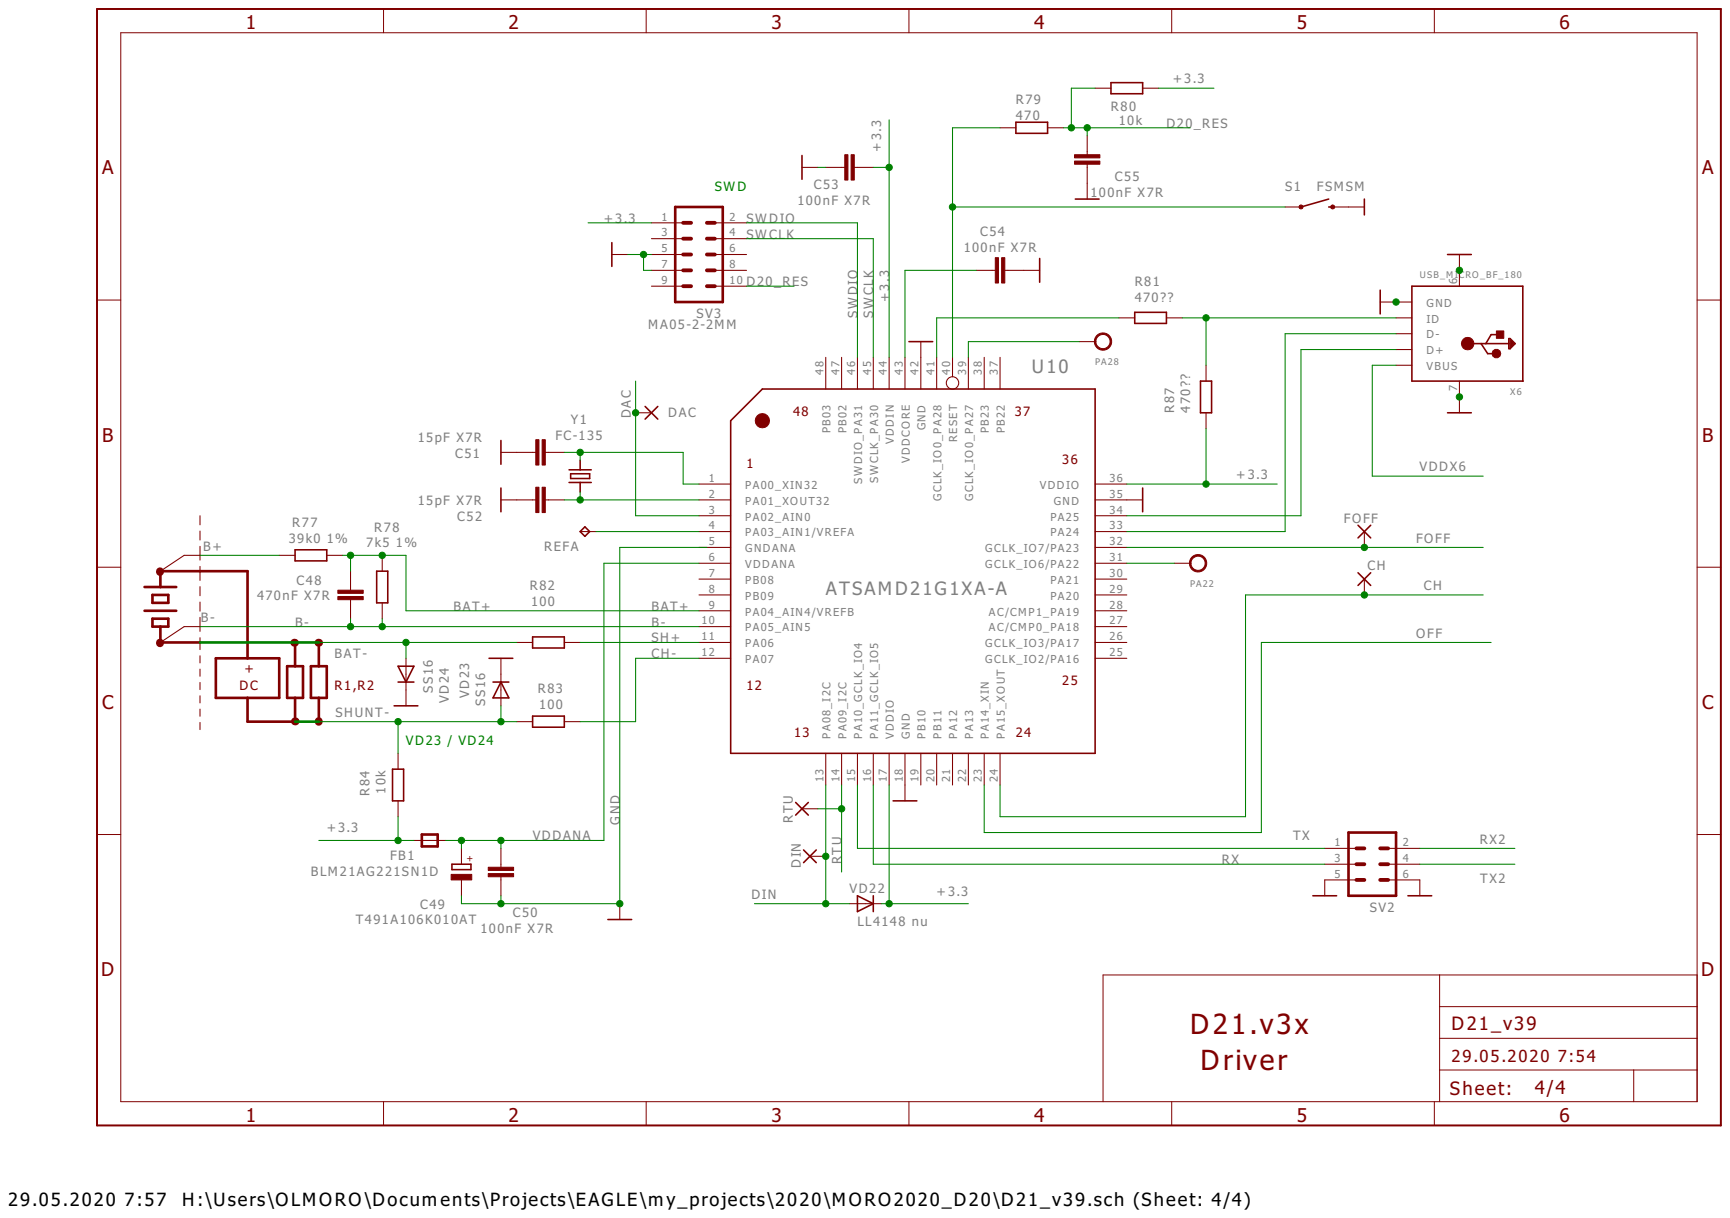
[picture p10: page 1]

D21.v3x Driver

Sheet: 4/4

29.05.2020 7:57 H:\Users\OLMORO\Documents\Projects\EAGLE\my_projects\2020\MORO2020_D20\D21_v39.sch (Sheet: 4/4)

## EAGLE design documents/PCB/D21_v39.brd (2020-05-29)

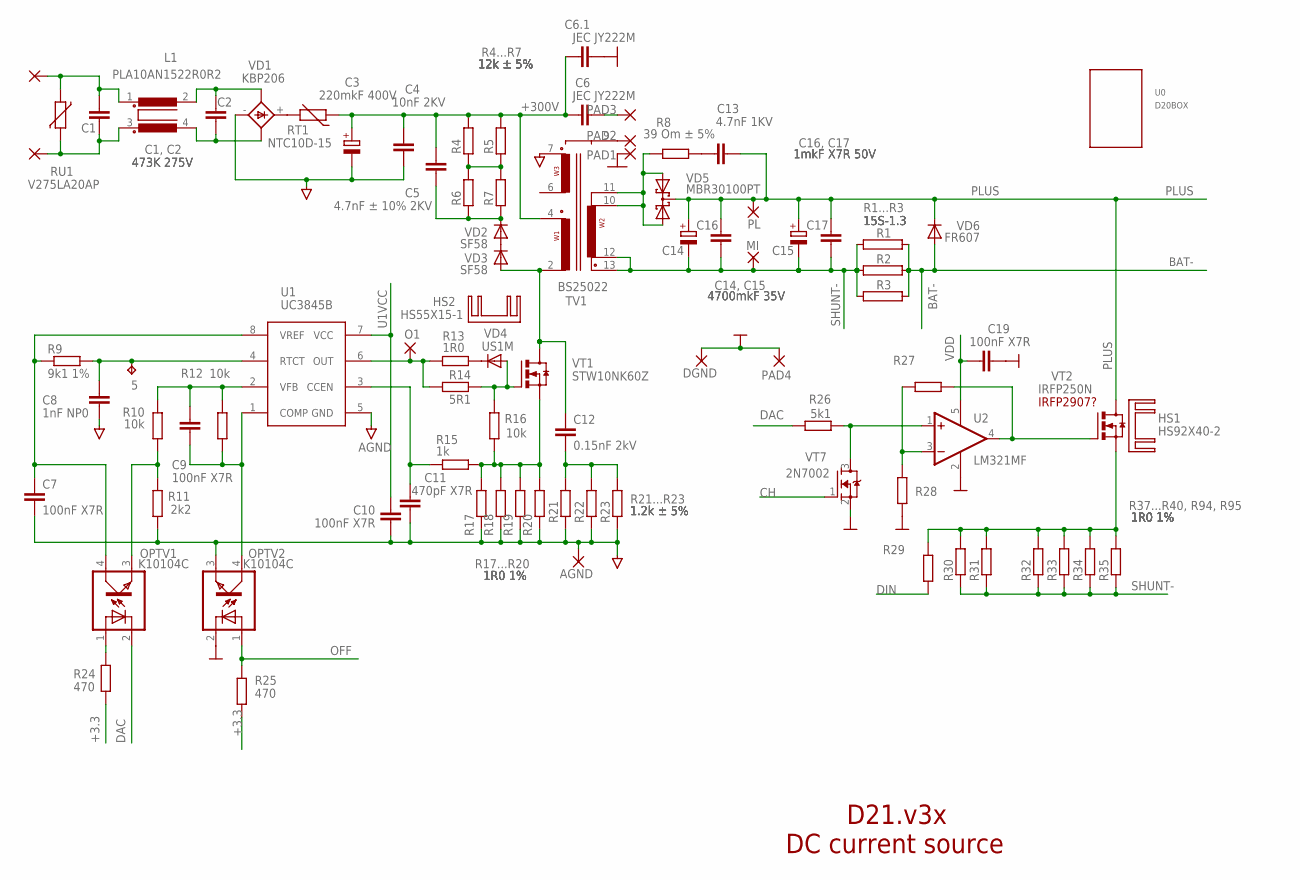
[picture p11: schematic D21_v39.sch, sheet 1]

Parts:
5: TPB1,27; B1,27
AGND: WIREPAD4,16O1,6; 4,16O1,6
C1, C2: 473K 275V; C150-054X183
C3: 220mkF 400V; EB25D
C4: 10nF 2KV; C102-043X133
C5: 4.7nF ± 10% 2KV; C102-064X133
C6, C6.1: JEC JY222M; C102-064X133
C7, C9, C19: 100nF X7R; C0603
C8: 1nF NP0; C0603
C10: 100nF X7R; C0805
C11: 470pF X7R; C0603
C12: 0.15nF 2kV; C075-032X103
C13: 4.7nF 1KV; C102-064X133
C14, C15: 4700mkF 35V; E7,5-18
C16, C17: 1mkF X7R 50V; C0805
DGND: WIREPAD4,16O1,6; 4,16O1,6
HS1: HS92X40-2; YS92X40
HS2: HS55X15-1; HS55X15
L1: PLA10AN1522R0R2; DK30
MI: WIREPAD4,16O1,6; 4,16O1,6
O1: WIREPAD1,6/0,8; 1,6/0,8
OPTV1, OPTV2: K10104C; SMD4-7
PAD1, PAD2, PAD3: SMD2; SMD1,27-2,54
PAD4: WIREPAD4,16O1,6; 4,16O1,6
PL: WIREPAD4,16O1,6; 4,16O1,6
R1, R2, R3: 15S-1.3
R4, R5, R6, R7: 12k ± 5%; 0515/20
R8: 39 Om ± 5%; 0515/20
R9: 9k1 1%; R0603
R10, R12, R16: 10k; R0603
R11: 2k2; R0603
R13: 1R0; R0805
R14: 5R1; R0805
R15: 1k; R0603
R17, R18, R19, R20, R30, R31, R32, R33, R34, R35: 1R0 1%; R2512
R21, R22, R23: 1.2k ± 5%; 0515/20
R24, R25: 470; R0603
R26: 5k1; R0603
R27, R28, R29: R-EU_R0603; R0603
RT1: NTC10D-15; NTC15
RU1: V275LA20AP; S10K11-H
TV1: BS25022
U0: D20BOX
U1: UC3845B; SO08
U2: LM321MF; SOT23-5
VD1: KBP206; 2KBP
VD2, VD3: SF58; DO201-15
VD4: US1M; SMADIODE
VD5: MBR30100PT; TO-247AD-V
VD6: FR607; P6-15
VT1: STW10NK60Z; TO-247AD-V
VT2: IRFP250N; TO-247AD-V
VT7: 2N7002; SOT23-R
X1: 220VAC

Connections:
10-11: R8.1, TV1.10, TV1.11, VD5.G (A1), VD5.S (A2)
+3.3: R24.2, R25.2; also elsewhere on the board
+300V: C3.+, C4.1, C5.1, C6.1, C6.1.1, R4.2, R5.2, RT1.1, TV1.4; also elsewhere on the board
AGND: AGND.1, C3.-, C4.2, C7.2, C8.2, C10.2, C11.2, OPTV2.3 (EMIT), R11.1, R17.1, R18.1, R19.1, R20.1, R21.1, R22.1, R23.1, TV1.7, U1.5 (GND), VD1.-; also elsewhere on the board
BAT-: R1.2, R2.2, R3.2, VD6.A; also elsewhere on the board
CH: VT7.1 (G); also elsewhere on the board
DAC: OPTV1.2 (C), R26.2; also elsewhere on the board
DIN: R29.2; also elsewhere on the board
DIN1: R29.1, R30.2, R31.2, R32.2, R33.2, R34.2, R35.2, VT2.S
GND: C6.1.2, C19.1, DGND.1, OPTV2.2 (C), PAD1.1, PAD4.1, R28.2, U2.2 (V-), VT7.2 (S); also elsewhere on the board
HS2: C5.2, R6.1, R7.1, VD2.C
unnamed: R4.1, R5.1, R6.2, R7.2
unnamed: VD2.A, VD3.C
unnamed: C12.1, TV1.2, VD3.A, VT1.D
unnamed: C12.2, R21.2, R22.2, R23.2
unnamed: C1.2, L1.3, RU1.2, X1.P$2 (2)
unnamed: RT1.2, VD1.+
unnamed: R14.2, R16.2, VD4.A, VT1.G
unnamed: PAD2.1, TV1.9
unnamed: R15.2, R16.1, R17.2, R18.2, R19.2, R20.2, VT1.S
unnamed: C2.1, L1.2, VD1.AC1
unnamed: C1.1, L1.1, RU1.1, X1.P$1 (1)
unnamed: C2.2, L1.4, VD1.AC2
unnamed: O1.1, R13.1, R14.1, U1.6 (OUT)
unnamed: R13.2, VD4.C
unnamed: OPTV1.1 (A), R24.1
unnamed: C11.1, R15.1, U1.3 (CCEN)
unnamed: C9.2, OPTV2.4 (COL), R12.1, U1.1 (COMP)
unnamed: C9.1, R10.2, R12.2, U1.2 (VFB)
unnamed: OPTV1.3 (EMIT), R10.1, R11.2
unnamed: C7.1, OPTV1.4 (COL), R9.1, U1.8 (VREF)
unnamed: 5.TP, C8.1, R9.2, U1.4 (RTCT)
unnamed: R27.1, U2.4 (OUT), VT2.G
unnamed: R27.2, R28.1, U2.3 (-IN)
unnamed: R26.1, U2.1 (+IN), VT7.3 (D)
unnamed: C6.2, PAD3.1
unnamed: C13.1, R8.2
OFF: OPTV2.1 (A), R25.1; also elsewhere on the board
PLUS: C13.2, C14.+, C15.+, C16.1, C17.1, PL.1, VD5.D (C), VD6.C, VT2.D; also elsewhere on the board
SHUNT-: C14.-, C15.-, C16.2, C17.2, MI.1, R1.1, R2.1, R3.1, R30.1, R31.1, R32.1, R33.1, R34.1, R35.1, TV1.12, TV1.13; also elsewhere on the board
U1VCC: C10.1, U1.7 (VCC); also elsewhere on the board
VDD: C19.2, U2.5 (V+); also elsewhere on the board

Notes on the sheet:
D21.v3x DC current source
R4...R7
R21...R23
R17...R20
R37...R40, R94, R95
C16, C17
C14, C15
R1...R3
C1, C2
IRFP2907?

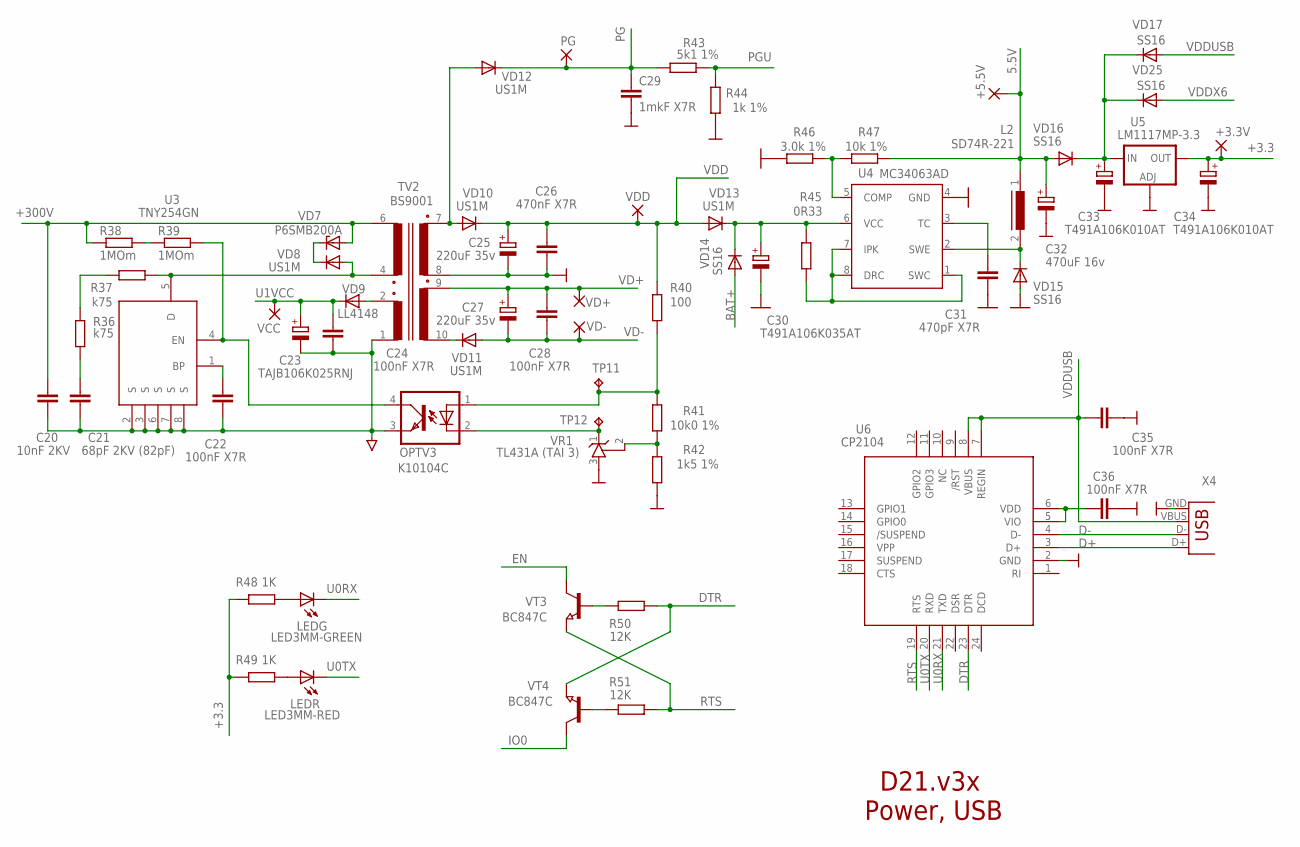
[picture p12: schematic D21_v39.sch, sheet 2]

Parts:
+3.3V, +5.5V: WIREPAD1,6/0,8; 1,6/0,8
C20: 10nF 2KV; C102-043X133
C21: 68pF 2KV (82pF); C050-024X044
C22, C24, C35, C36: 100nF X7R; C0603
C23: TAJB106K025RNJ; CT6032
C25, C27: 220uF 35v; E3,5-8
C26: 470nF X7R; C0805
C28: 100nF X7R; C0805
C29: 1mkF X7R; C0805
C30: T491A106K035AT; CT6032
C31: 470pF X7R; C0603
C32: 470uF 16v; E5-8,5
C33, C34: T491A106K010AT; CT3216
L2: SD74R-221; DR74
LEDG: LED3MM-GREEN; LED3MM-H7MMG
LEDR: LED3MM-RED; LED3MM-H7MMR
OPTV3: K10104C; SMD4-7
PG: WIREPAD1,6/0,8; 1,6/0,8
R36, R37: k75; R1206
R38, R39: 1MOm; R1206
R40: 100; R0603
R41: 10k0 1%; R0603
R42: 1k5 1%; R0603
R43: 5k1 1%; R0603
R44: 1k 1%; R0603
R45: 0R33; R0603
R46: 3.0k 1%; R0603
R47: 10k 1%; R0603
R48, R49: 1K; R0603
R50, R51: 12K; R0603
TP11, TP12: TPB1,27; B1,27
TV2: BS9001
U3: TNY254GN; SMD-8
U4: MC34063AD; SO08
U5: LM1117MP-3.3; SOT223-W
U6: CP2104; QFN-24
VCC: WIREPAD1,6/0,8; 1,6/0,8
VD7: P6SMB200A; SMB
VD8, VD10, VD11, VD12, VD13: US1M; SMADIODE
VD9: LL4148; SOD80C
VD14, VD15, VD16, VD17, VD25: SS16; SMADIODE
VD+: WIREPAD1,6/0,8; 1,6/0,8
VD-: WIREPAD1,6/0,8; 1,6/0,8
VDD: WIREPAD1,6/0,8; 1,6/0,8
VR1: TL431A (TAI 3); SOT23
VT3, VT4: BC847C; SOT23
X4: USB-B; USB-B-H

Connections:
5.5V: +5.5V.1, C32.+, L2.1, R47.2, VD16.A; also elsewhere on the board
+3.3: +3.3V.1, C34.+, R48.2, R49.2, U5.2 (OUT); also elsewhere on the board
+300V: C20.1, R38.1, TV2.6, VD7.A; also elsewhere on the board
AGND: C20.2, C21.2, C22.2, C23.-, C24.2, OPTV3.3 (EMIT), TV2.1, U3.2 (S), U3.3 (S), U3.6 (S), U3.7 (S), U3.8 (S); also elsewhere on the board
BAT+: VD14.A; also elsewhere on the board
D+: U6.3 (D+), X4.D+
D-: U6.4 (D-), X4.D-
DTR: R50.2, U6.23 (DTR), VT4.2 (E)
EN: VT3.3 (C); also elsewhere on the board
GND: C25.-, C26.2, C29.2, C30.-, C31.2, C32.-, C33.-, C34.-, C35.2, C36.2, R42.2, R44.1, R46.1, TV2.8, U4.4 (GND), U5.1 (ADJ), U6.2 (GND), VD15.A, VR1.3 (A), X4.GND; also elsewhere on the board
IO0: VT4.3 (C); also elsewhere on the board
unnamed: R36.2, R37.1
unnamed: C36.1, U6.5 (VIO), U6.6 (VDD)
unnamed: R37.2, TV2.4, U3.5 (D), VD8.A
unnamed: C21.1, R36.1
unnamed: C22.1, U3.1 (BP)
unnamed: R38.2, R39.1
unnamed: OPTV3.4 (COL), R39.2, U3.4 (EN)
unnamed: OPTV3.1 (A), R40.2, R41.1, TP11.TP
unnamed: TV2.2, VD9.A
unnamed: VD7.C, VD8.C
unnamed: TV2.10, VD11.C
unnamed: TV2.7, VD10.A, VD12.A
unnamed: C30.+, R45.1, U4.6 (VCC), VD13.C, VD14.C
unnamed: LEDR.A, R49.1
unnamed: LEDG.A, R48.1
unnamed: R45.2, U4.1 (SWC), U4.7 (IPK), U4.8 (DRC)
unnamed: L2.2, U4.2 (SWE), VD15.C
unnamed: C31.1, U4.3 (TC)
unnamed: R46.2, R47.1, U4.5 (COMP)
unnamed: C33.+, U5.3 (IN), VD16.C, VD17.C, VD25.C
unnamed: R41.2, R42.1, VR1.2 (R)
unnamed: R51.1, VT4.1 (B)
unnamed: R50.1, VT3.1 (B)
unnamed: OPTV3.2 (C), TP12.TP, VR1.1 (C)
PG: C29.1, PG.1, R43.1, VD12.C; also elsewhere on the board
PGU: R43.2, R44.2; also elsewhere on the board
RTS: R51.2, U6.19 (RTS), VT3.2 (E)
U0RX: LEDG.K (C), U6.21 (TXD); also elsewhere on the board
U0TX: LEDR.K (C), U6.20 (RXD); also elsewhere on the board
U1VCC: C23.+, C24.1, VCC.1, VD9.C; also elsewhere on the board
VD+: C27.+, C28.1, TV2.9, VD+.1; also elsewhere on the board
VD-: C27.-, C28.2, VD11.A, VD-.1; also elsewhere on the board
VDD: C25.+, C26.1, R40.1, VD10.C, VD13.A, VDD.1; also elsewhere on the board
VDDUSB: C35.1, U6.7 (REGIN), U6.8 (VBUS), VD17.A, X4.VBUS
VDDX6: VD25.A; also elsewhere on the board

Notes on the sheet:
D21.v3x Power, USB

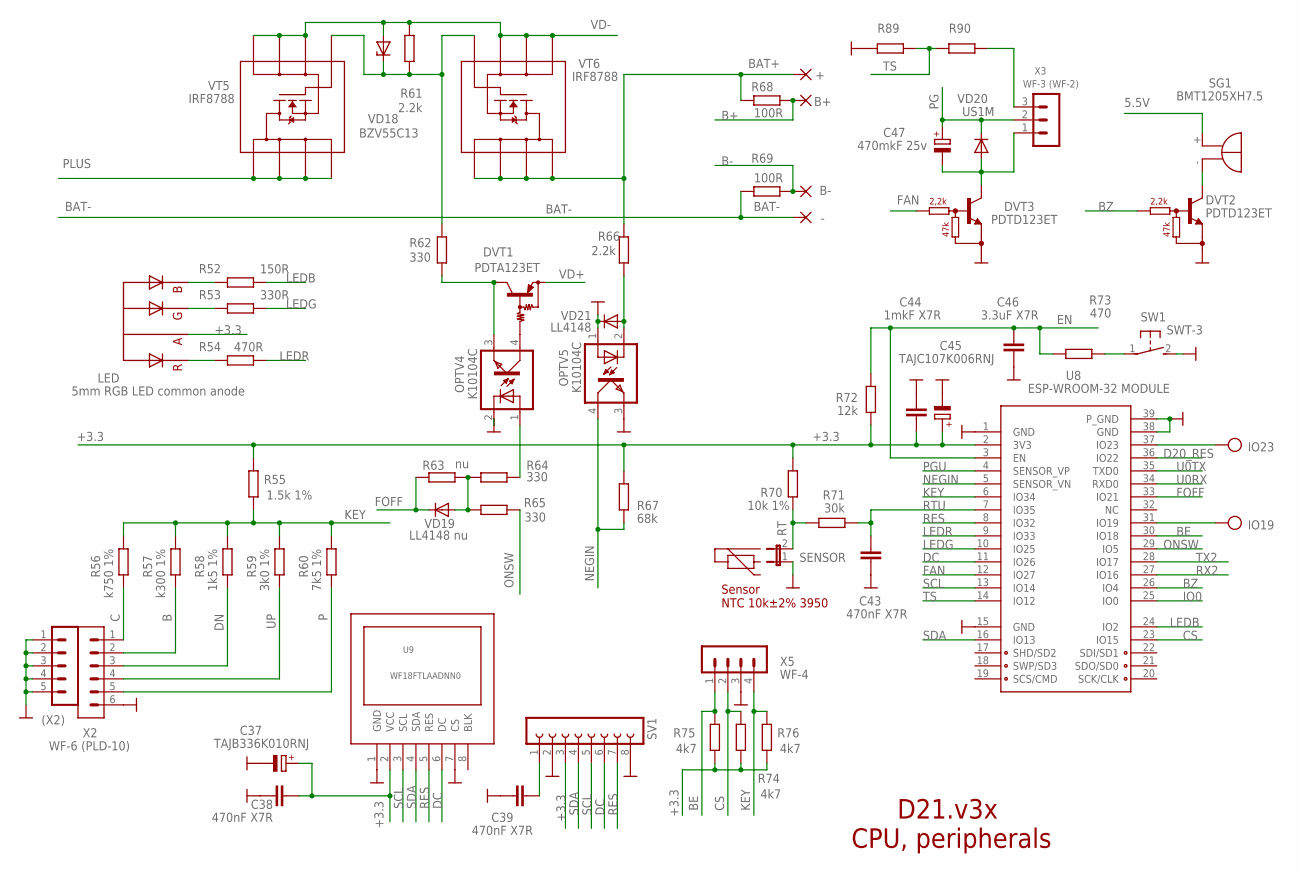
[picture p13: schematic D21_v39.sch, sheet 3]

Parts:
(X2): MA05-1
+: +; WIREPAD8_3
-: -; WIREPAD8_3
B+: WIREPAD4,16O1,6; 4,16O1,6
B-: WIREPAD4,16O1,6; 4,16O1,6
C37: TAJB336K010RNJ; CT6032
C38, C39, C43: 470nF X7R; C0805
C44: 1mkF X7R; C0805
C45: TAJC107K006RNJ; CT3528
C46: 3.3uF X7R; C0603
C47: 470mkF 25v; E3,5-8
DVT1: PDTA123ET; SC59-BEC
DVT2, DVT3: PDTD123ET; SOT23-BEC
IO19, IO23: TESTPOINTROUND1MM; TESTPOINT_ROUND_1MM
LED: 5mm RGB LED common anode; LED5MMRGB
OPTV4, OPTV5: K10104C; SMD4-7
R52: 150R; R0603
R53: 330R; R0603
R54: 470R; R0603
R55: 1.5k 1%; R0603
R56: k750 1%; R0603
R57: k300 1%; R0603
R58: 1k5 1%; R0603
R59: 3k0 1%; R0603
R60: 7k5 1%; R0603
R61, R66: 2.2k; R0603
R62, R64, R65: 330; R0603
R63: nu; R0603
R67: 68k; R0603
R68, R69: 100R; R0603
R70: 10k 1%; R0603
R71: 30k; R0603
R72: 12k; R0603
R73: 470; R0603
R74, R75, R76: 4k7; R0603
R89, R90: R-EU_R0603; R0603
SENSOR: JP1E; JP1
SG1: BMT1205XH7.5
SV1: FE08-1; FE08
SW1: SWT-3; B3F-31XX
U8: ESP-WROOM-32 MODULE; ESP-WROOM-32MORO
U9: WF18FTLAADNN0; TFT_1_8
VD18: BZV55C13; SOD80C
VD19: LL4148 nu; SOD80C
VD20: US1M; SMADIODE
VD21: LL4148; SOD80C
VT5, VT6: IRF8788; SO-8
X2: WF-6 (PLD-10); WF-6
X3: WF-3 (WF-2); WF-3
X5: WF-4

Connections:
5.5V: SG1.+; also elsewhere on the board
+3.3: C37.+, C38.1, C44.1, C45.+, LED.P$3 (A), R55.2, R67.1, R70.1, R72.1, R74.1, R75.1, R76.1, SV1.3, U8.2 (3V3), U9.2 (VCC); also elsewhere on the board
B: R57.1, X2.2
B+: B+.1, R68.1; also elsewhere on the board
B-: B-.1, R69.1; also elsewhere on the board
BAT+: +.P$1, R66.1, R68.2, VT6.5 (D), VT6.6 (D), VT6.7 (D), VT6.8 (D); also elsewhere on the board
BAT-: -.P$1, R69.2; also elsewhere on the board
BE: R75.2, U8.30 (IO18), X5.1
BLK: U9.8 (BLK)
BZ: DVT2.B, U8.26 (IO4)
C: R56.2, X2.1
CS: R74.2, U8.23 (IO15), X5.2
D20_RES: U8.36 (IO22); also elsewhere on the board
DC: SV1.6, U8.11 (IO26), U9.6 (DC)
DN: R58.1, X2.3
EN: C46.2, R72.2, R73.1, U8.3 (EN); also elsewhere on the board
FAN: DVT3.B, U8.12 (IO27)
FOFF: R63.1, U8.33 (IO21), VD19.C; also elsewhere on the board
G: R61.1, R62.1, VD18.C, VT5.4 (G), VT6.4 (G)
GND: (X2).1, (X2).2, (X2).3, (X2).4, (X2).5, C37.-, C38.2, C39.2, C43.2, C44.2, C45.-, C46.1, DVT2.E, DVT3.E, OPTV4.2 (C), OPTV5.1 (A), OPTV5.3 (EMIT), R89.2, SENSOR.1, SV1.2, SV1.8, SW1.2 (S), U8.1 (GND), U8.15 (GND), U8.38 (GND), U8.39 (P_GND), U9.1 (GND), U9.7 (CS), VD21.C, X2.6, X5.3; also elsewhere on the board
IO0: U8.25 (IO0); also elsewhere on the board
KEY: R55.1, R56.1, R57.2, R58.2, R59.2, R60.1, R76.2, U8.6 (IO34), X5.4
LEDB: R52.1, U8.24 (IO2)
LEDG: R53.1, U8.10 (IO25)
LEDR: R54.1, U8.9 (IO33)
unnamed: R90.1, X3.3
unnamed: C39.1, SV1.1
unnamed: DVT2.C, SG1.-
unnamed: LED.P$2 (GREEN), R53.2
unnamed: LED.P$1 (BLUE), R52.2
unnamed: LED.P$4 (RED), R54.2
unnamed: C47.-, DVT3.C, VD20.A, X3.1
unnamed: DVT1.C, OPTV4.3 (EMIT), R62.2
unnamed: DVT1.B, OPTV4.4 (COL)
unnamed: OPTV5.2 (C), R66.2, VD21.A
unnamed: R63.2, R64.1, R65.2, VD19.A
unnamed: IO23.P$1, U8.37 (IO23)
unnamed: IO19.P$1, U8.31 (IO19)
unnamed: R73.2, SW1.1
NEGIN: OPTV5.4 (COL), R67.2, U8.5 (SENSOR_VN)
ONSW: R65.1, U8.29 (IO5)
P: R60.2, X2.5
PG: C47.+, VD20.C, X3.2; also elsewhere on the board
PGU: U8.4 (SENSOR_VP); also elsewhere on the board
PLUS: VT5.5 (D), VT5.6 (D), VT5.7 (D), VT5.8 (D); also elsewhere on the board
RES: SV1.7, U8.8 (IO32), U9.5 (RES)
RT: R70.2, R71.1, SENSOR.2
RTU: C43.1, R71.2, U8.7 (IO35); also elsewhere on the board
RX2: U8.27 (IO16); also elsewhere on the board
SCL: SV1.5, U8.13 (IO14), U9.3 (SCL)
SDA: SV1.4, U8.16 (IO13), U9.4 (SDA)
TOV2: OPTV4.1 (A), R64.2
TS: R89.1, R90.2, U8.14 (IO12)
TX2: U8.28 (IO17); also elsewhere on the board
U0RX: U8.34 (RXD0); also elsewhere on the board
U0TX: U8.35 (TXD0); also elsewhere on the board
UP: R59.1, X2.4
VD+: DVT1.E; also elsewhere on the board
VD-: R61.2, VD18.A, VT5.1 (S), VT5.2 (S), VT5.3 (S), VT6.1 (S), VT6.2 (S), VT6.3 (S); also elsewhere on the board

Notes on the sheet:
Sensor NTC 10k±2% 3950
D21.v3x CPU, peripherals

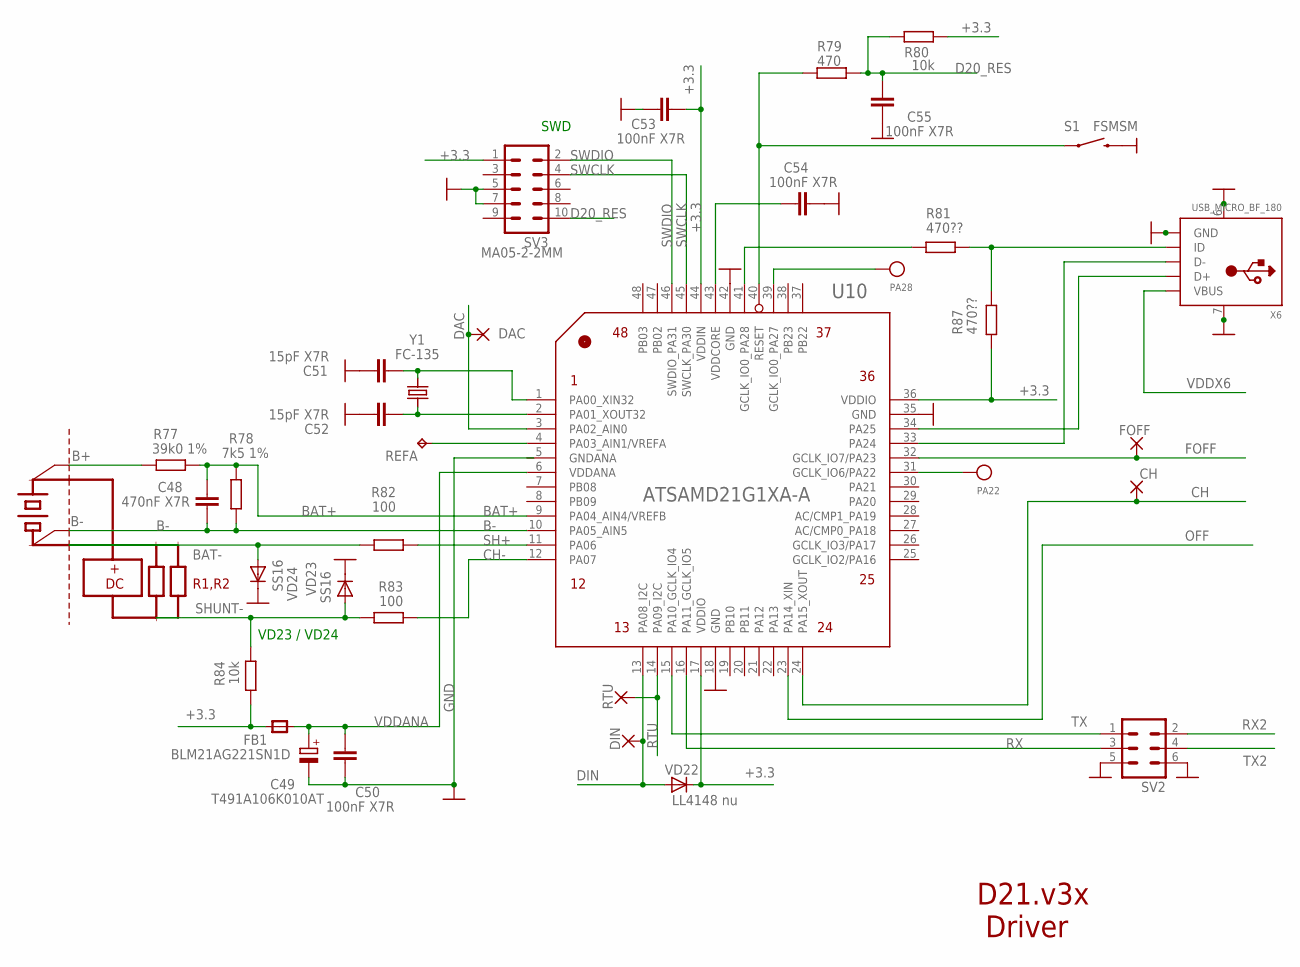
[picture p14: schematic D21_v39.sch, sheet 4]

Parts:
C48: 470nF X7R; C0805
C49: T491A106K010AT; CT3216
C50, C53, C54: 100nF X7R; C0603
C51, C52: 15pF X7R; C0603
C55: 100nF X7R; C0805
CH: WIREPAD1,6/0,8; 1,6/0,8
DAC: WIREPAD1,6/0,8; 1,6/0,8
DIN: WIREPAD1,6/0,8; 1,6/0,8
FB1: BLM21AG221SN1D; 0805
FOFF: WIREPAD1,6/0,8; 1,6/0,8
PA22, PA28: TESTPOINTROUND1MM; TESTPOINT_ROUND_1MM
R77: 39k0 1%; R0603
R78: 7k5 1%; R0603
R79: 470; R0603
R80, R84: 10k; R0603
R81, R87: 470??; R0603
R82, R83: 100; R0603
REFA: TPB1,27; B1,27
RTU: WIREPAD1,6/0,8; 1,6/0,8
S1: FSMSM; TACTILE-SWITCH-1101NE
SV2: MA03-2
SV3: MA05-2-2MM; MA5-2-2MM
U10: ATSAMD21G1XA-A; LQFP48_W
VD22: LL4148 nu; SOD80C
VD23, VD24: SS16; SMADIODE
X6: USB_MICRO_BF_180; USB_MICRO_180
Y1: FC-135; SMD03215C2

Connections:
+3.3: C53.1, FB1.1, R80.2, R84.2, R87.1, SV3.1, U10.17 (VDDIO), U10.36 (VDDIO), U10.44 (VDDIN), VD22.C; also elsewhere on the board
B+: R77.2; also elsewhere on the board
B-: C48.2, R78.2, U10.10 (PA05_AIN5); also elsewhere on the board
BAT+: C48.1, R77.1, R78.1, U10.9 (PA04_AIN4/VREFB); also elsewhere on the board
BAT-: R82.2, VD24.A; also elsewhere on the board
CH: CH.1, U10.24 (PA15_XOUT); also elsewhere on the board
CH-: R83.1, U10.12 (PA07)
D20_RES: C55.2, R79.2, R80.1, SV3.10; also elsewhere on the board
DAC: DAC.1, U10.3 (PA02_AIN0); also elsewhere on the board
DIN: DIN.1, U10.13 (PA08_I2C), VD22.A; also elsewhere on the board
FOFF: FOFF.1, U10.32 (GCLK_IO7/PA23); also elsewhere on the board
GND: C49.-, C50.2, C51.2, C52.2, C53.2, C54.1, C55.1, S1.P$2 (2), SV2.5, SV2.6, SV3.5, SV3.7, U10.5 (GNDANA), U10.18 (GND), U10.35 (GND), U10.42 (GND), VD23.C, VD24.C, X6.5 (GND), X6.6, X6.7; also elsewhere on the board
unnamed: R79.1, S1.P$1 (1), U10.40 (RESET)
unnamed: C52.1, U10.2 (PA01_XOUT32), Y1.P$1 (1)
unnamed: REFA.TP, U10.4 (PA03_AIN1/VREFA)
unnamed: C51.1, U10.1 (PA00_XIN32), Y1.P$2 (2)
unnamed: U10.33 (PA24), X6.2 (D-)
unnamed: U10.34 (PA25), X6.3 (D+)
unnamed: R81.2, R87.2, X6.4 (ID)
unnamed: PA28.P$1, U10.39 (GCLK_IO0_PA27)
unnamed: PA22.P$1, U10.31 (GCLK_IO6/PA22)
OFF: U10.23 (PA14_XIN); also elsewhere on the board
PA28: R81.1, U10.41 (GCLK_IO0_PA28)
RTU: RTU.1, U10.14 (PA09_I2C); also elsewhere on the board
RX: SV2.3, U10.16 (PA11_GCLK_IO5)
RX2: SV2.2; also elsewhere on the board
SH+: R82.1, U10.11 (PA06)
SHUNT-: R83.2, R84.1, VD23.A; also elsewhere on the board
SWCLK: SV3.4, U10.45 (SWCLK_PA30)
SWDIO: SV3.2, U10.46 (SWDIO_PA31)
TX: SV2.1, U10.15 (PA10_GCLK_IO4)
TX2: SV2.4; also elsewhere on the board
VDDANA: C49.+, C50.1, FB1.2, U10.6 (VDDANA)
VDDCORE: C54.2, U10.43 (VDDCORE)
VDDX6: X6.1 (VBUS); also elsewhere on the board

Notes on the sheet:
D21.v3x Driver
R1,R2
SWD
+ DC
VD23 / VD24

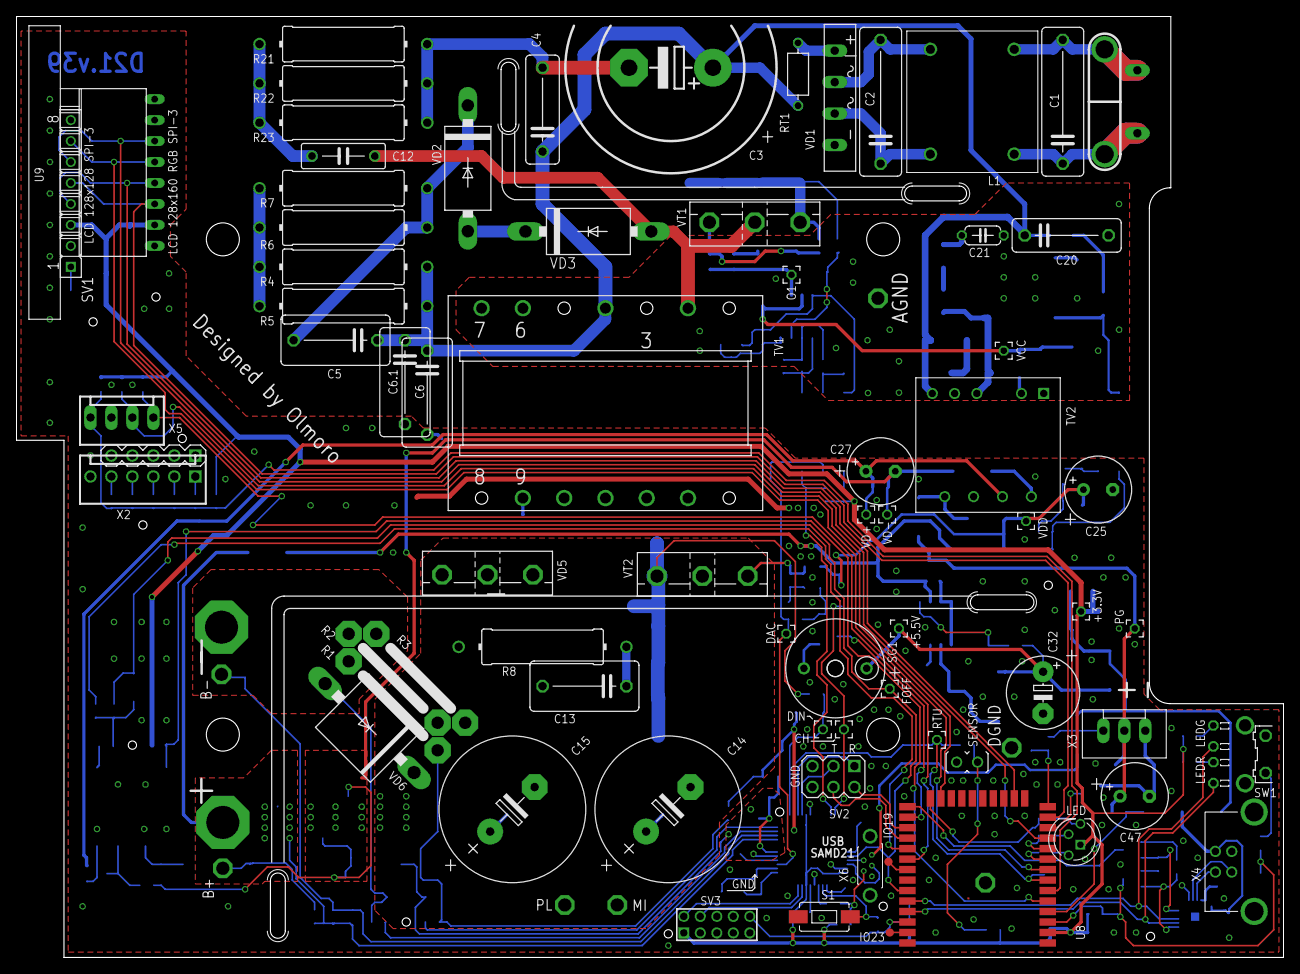
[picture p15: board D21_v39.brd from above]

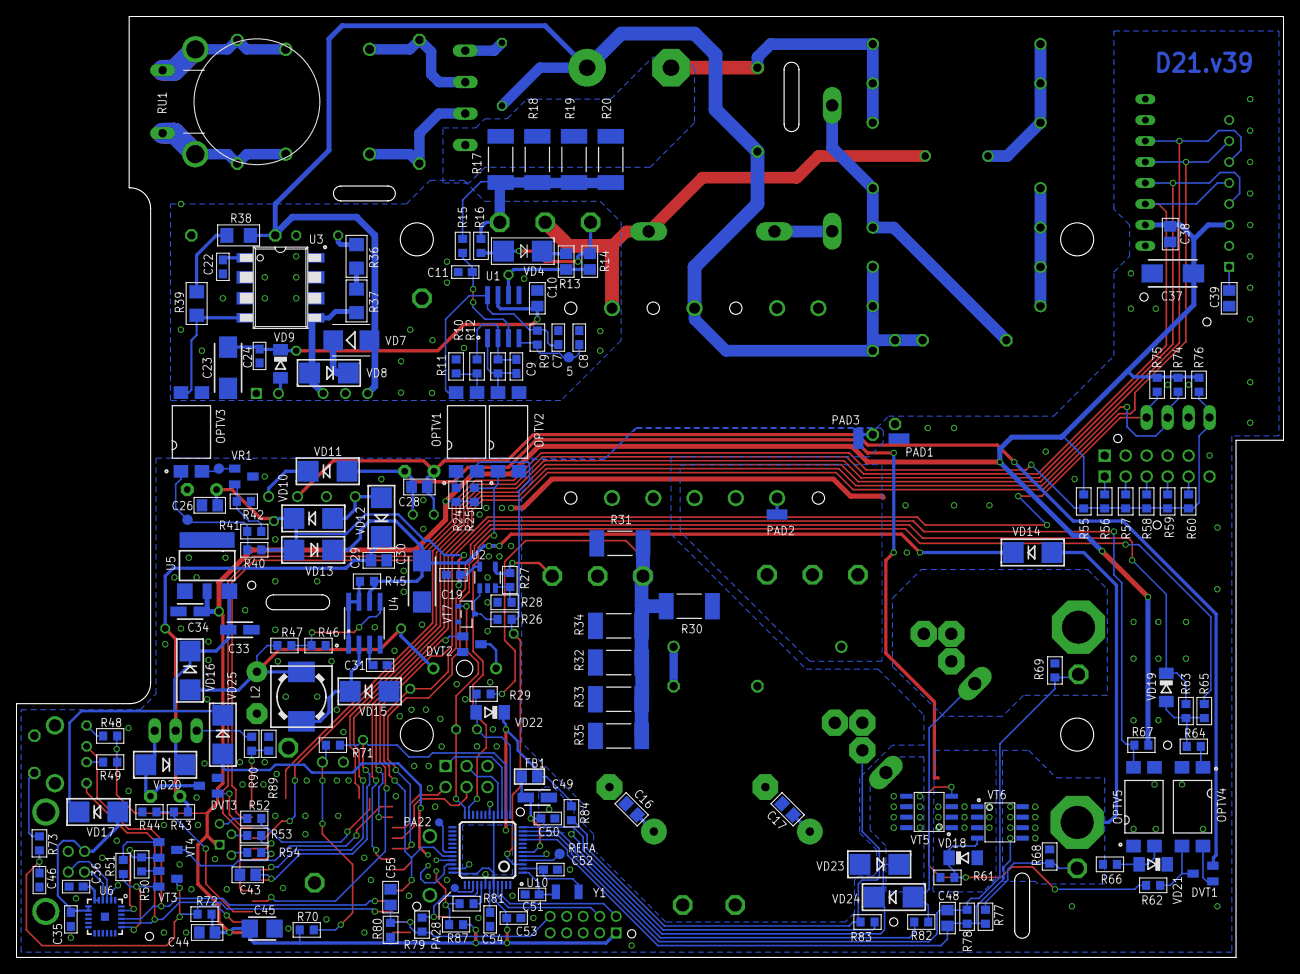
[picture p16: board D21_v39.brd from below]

Board: 2 copper layers, 153.5 x 114.0 mm, 250 parts (165 on the bottom side), 144 nets.

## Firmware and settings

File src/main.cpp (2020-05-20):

/*
    https://manualzz.com/doc/11587480/using-atsamd21-sercom-for-more-spi--i2c-and-serial-ports
    Using ATSAMD21 SERCOM for more SPI, I2C and Serial ports

    View detail for Atmel AT11628: SAM D21 SERCOM I2C Configuration

    Вариант с UART
*/

#include "board/mpins.h"
#include "wake/wake.h"
#include "commands/commands.h"
#include "power/power_reg.h"
#include "adc/adc.h"

#include <Arduino.h>            // N. порядок не нарушать!
#include "wiring_private.h"     // N=1.


void setup() 
{
  SerialUSB.begin(115200);
  delay(1);

  // инициализация UART порта ( D0:PA11/UART-RX, D1:PA10/UART-TX )
  Serial1.begin(115200);            // это не порт монитора

  portsInit();
  wakeInit( 0x00, 500 );            // обмен без адреса, время ожидания, ms
  initAdc(0);                       // не обязательно
  
}

void loop() 
{
    // Измерения и регулирование
  doMeasure();   // считать, преобразовать, задать следующее и запустить
  
    // Обслуживание интерфейса
  if( Serial1.available() )     // В буфере приема есть принятые байты, не факт, что пакет полный
  {
    wakeRead();                 // Пока не принят весь пакет, время ожидания ограничено (пока 1с)
  }

  doState1();
  doState2();
  doCommand();                  // Если ненулевая, будет исполнена
}

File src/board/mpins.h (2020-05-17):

#ifndef _MPINS_H_
#define _MPINS_H_
/*
* https://github.com/BLavery/SAMD21-M0-Mini
* select the board: Tools/Board = Arduino SAMD / "Arduino Zero (Native USB Port)".
* Double-click the board reset button. Upload. See if a LED blinks.
* explain a bit:
* 1. The Arduino bootloader uses double click on reset button to enter flash upload mode. Single
*    reset enters normal running mode. (Boot0/1 jumpers, like STM32 uses, are not used on the SAMD.)
* 2. The serial/bossac mode of USB upload is included in the Arduino install.
* 3. The regular user LED is missing. So we choose one of the TX/RX LEDs. For the moment, 
*    the Arduino sketch is NOT otherwise driving these as TX/RX indicators (see above), 
*    so we can re-employ them.
* 4. But what pin or GPIO number? For this board, reference the pins as 0-26 or A0-A5. Not D25, 
*    nor PB03 or PB3.
*
* https://github.com/arduino/ArduinoCore-samd/pull/374/files
* additional analog inputs: A6-A11 #374 
*/

//#include "SAMD_AnalogCorrection.h"
#include "stdint.h"

namespace MPins
{

//#include <Arduino.h>

//                q920_name      arduino_pin  M0-MINI   SAMD21_name
constexpr uint8_t uart_rx           =    0;    // D0   PA11/UART-RX             
constexpr uint8_t uart_tx           =    1;    // D1   PA10/UART-TX  
constexpr uint8_t off_pin           =    2;    // D4   PA14
constexpr uint8_t d3_pin            =    3;    // D3   PA09
constexpr uint8_t rtu_pin           =   50;    // D3   additional analog as PA09
constexpr uint8_t rtu_mux           =    9;    // D3   additional analog as PA09
constexpr uint8_t d2_pin            =    4;    // D2   PA08 nu
constexpr uint8_t din_pin           =   51;    // D2   additional analog as PA08
constexpr uint8_t din_mux           =    8;    // D2   additional analog as PA08
constexpr uint8_t ch_pin            =    5;    // D5   PA15
constexpr uint8_t d8_pin            =    8;    // D8   PA06 nu
constexpr uint8_t d9_pin            =    9;    // D9   PA07 nu

constexpr uint8_t shunt_plus_pin    =   46;    // D8   additional analog as PA06
constexpr uint8_t shunt_minus_pin   =   47;    // D9   additional analog as PA07
constexpr uint8_t shunt_plus_mux    =    6;    // D8   additional analog as PA06
constexpr uint8_t shunt_minus_mux   =    7;    // D9   additional analog as PA07

constexpr uint8_t ss_pin            =   10;    // D10  PA18
constexpr uint8_t mosi_pin          =   11;    // D11  PA16
constexpr uint8_t miso_pin          =   12;    // D12  PA19
constexpr uint8_t sck_pin           =   13;    // D13  PA17

constexpr uint8_t dac_pin           =   14;    // A0   PA02
constexpr uint8_t bat_plus_pin      =   17;    // A3   PA04
constexpr uint8_t bat_minus_pin     =   18;    // A4   PA05
constexpr uint8_t bat_plus_mux      =    4;    // A3   PA04
constexpr uint8_t bat_minus_mux     =    5;    // A4   PA05
constexpr uint8_t icsp_miso         =   22;    //  1   PA12/MISO ICSP  !! На схеме 2
constexpr uint8_t icsp_mosi         =   23;    //  4   PB10/MOSI ICSP              3
constexpr uint8_t icsp_sck          =   24;    //  3   PB11/SCK  ICSP              4
constexpr uint8_t led_rx            =   25;    // no   PB03/LED1 (LED_BUILTIN, LED_RX)
constexpr uint8_t led_tx            =   26;    // no   PA27/LED2 (LED_TX)
constexpr uint8_t foff_pin          =   21;    // D21  PA23

// Not used
//    6    // D6   PA20       // d21
//    7    // D7   PA21       // d21
//   15    // A1   PB08       // d21
//   16    // A2   PB09       // d21
//   19    // A5   PB02       // d21
//   20    // D20  PA22/SDA
//   21    // D21  PA23/SCL

};

#endif // !_MPINS_H_

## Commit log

2020-04-16 Передача пакета
2020-04-18 ПИД commands
2020-04-25 PID commands
2020-04-28 Read probes
2020-04-29 ADC commands
2020-05-05 adc comm 50 51 52
2020-05-18 Команды управления процессами
2020-05-20 Оптимизация
2020-05-22 PID control
2020-05-27 PCB new
    [D21_v38.brd, D21_v38.sch]

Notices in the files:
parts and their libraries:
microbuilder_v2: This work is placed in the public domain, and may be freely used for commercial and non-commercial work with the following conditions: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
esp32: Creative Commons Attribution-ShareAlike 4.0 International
